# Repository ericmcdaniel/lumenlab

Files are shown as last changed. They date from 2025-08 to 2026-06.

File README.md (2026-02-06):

<p align="center">
  <picture>
    <source media="(prefers-color-scheme: dark)" srcset="assets/lumenlab-logo-dark.png">
    <source media="(prefers-color-scheme: light)" srcset="assets/lumenlab-logo.png">
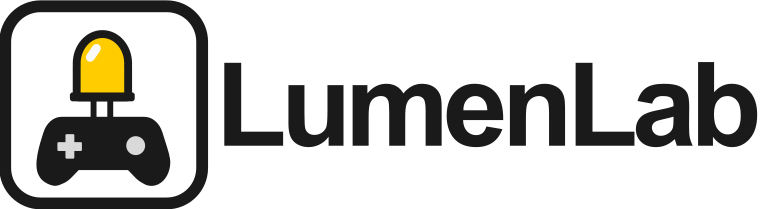
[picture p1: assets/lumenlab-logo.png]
LumenLab Logo
    
  </picture>
</p>
<p align="center">Transforming pixels into a playground</p>

---

__LumenLab__ is an LED strip gaming and entertainment platform designed to transform your space into an interactive playground of light. Powered by an ESP32 microcontroller, displayed through a NeoPixel addressable LED strip, and controlled by a PlayStation 3 game controller, LumenLab brings simple, one-dimensional retro arcade-style games, animations, and ambient lighting to life.
<br>

# Features

LumenLab is composed of two modes. The central mode is its suite of games, but the platform also supports animations and ambient lighting, called scenes. After all it's still an LED strip!

## Games
Using an LED strip as a gaming platform is a unique concept due to the constraint of only having one dimension to interact with. Since *only* the landscape x-axis is available, this constraint compels players to apply creative interpretation during gameplay. This of course is not a modern, feature rich AAA blockbuster with 4K graphics, immersing you in the vision of a world crafted by others. Instead, LumenLab's restriction subtly encourages players to philosophically revisit what it *really* means to play a game down to the core. In its purest form, a game player follows rules and explores boundaries in pursuit of a goal. Gamers encounter conflict and must experiment and adapt to their environment to overcome obstacles. LumenLab forces players to abstractly experience digital gaming at its rawest, most atomic form: structured uncertainty and strategy until mastery is achieved. This has become the manifesto of the LumenLab. **Every individual playing its games has a unique mental concept of what they're experiencing.**

Because LumenLab is restricted to a single dimension composed of an array of LEDs, it's aesthetically reminiscent of retro arcade games. However, LumenLab exploits capabilities unavailable on old 8-bit game consoles. These capabilities include its ability to generate any arbitrary RGB color instead of being limited to 256 colors. Additionally, its UI takes advantage of the broad range of controls and state offered by the PS3 controller such as the number of buttons available and precise analog joy stick/trigger positions, contrasting from a cabinet arcade with only four discrete buttons. There are over six games, each detailed below.

| **Title** | **Description** |
| --- | --- |
| **Recall** |*Recall* is an adaptation of Hasbro's fifty-year-old game [*Simon*](https://en.wikipedia.org/wiki/Simon_(game)), chosen for its familiarity and simplicity. Players easily recognize the format, making it a natural fit for LumenLab’s constraints. Similar to the original, the LED strip flashes a color, and the player must press the matching button on the PS3 controller. Each round adds another color to the sequence, which must be recalled in full and in order.|
| **Phase Evasion** | *Phase Evasion* is a fast, colorful test of reflexes and hand-eye coordination. You are a color-shifting specter that is being pursued by colorful flares. You must match their color at the right moment to phase through them to evade. Gems are scattered throughout periodically. Quickly move over and grab them for bonus points if you dare. As the speed climbs and the screen fills with color, quick reactions and bold moves are the only way to stay in the game. |
| **Light Strike** | *Light Strike* combines the spirit of Atari's [*Space Invaders*](https://en.wikipedia.org/wiki/Space_Invaders) with elements of [*Asteroids*](https://en.wikipedia.org/wiki/Asteroids_(video_game)). As a lone agent in deep space, you enounter waves of predators approaching you from directions sides at varying speeds. Moving freely across the x-axis, and your survival requires defending yourself with your laser pistol. Conserve your ammunition however, your weapon can only fire so many rounds a minute!<br><br>*In development.* |
| **Reflex** | *Reflex* is a fast-moving inspired by the modern arcade game [*Pop the Lock*](https://www.baytekent.com/pop-the-lock/), testing precision and timing under pressure. A moving marker sweeps across the field toward a shifting target. Fire at the perfect moment to score a hit. Each success quickens the pace, reverses the marker's direction, and relocates the target to a new random location. Survive fifty flawless shots to win.<br><br>*In development.* |
| **Spectrum** | *Spectrum* tests your perception of color and precision of control. A random RGB color appears on one end of the display, and you must use the analog stick to recreate it as closely as possible. The closer your match, the higher your score.<br><br>*In development* |
| **Pursuit** | *In development.* Details to be provided soon. |

There are more game ideas in the works, and ideas for some *two-player* games are being considered.

## Scenes

An LED strip entertainment platform would not be complete if it did not include animations and special effects libraries. Inspired by the [WLED project](https://kno.wled.ge/), LumenLab is able to create captivating scenes. Many of them are interactive, for example moving the joystick can change the color, or pressing the directional buttons can change timing.
| **Title** | **Description** |
| --- | --- |
| **Canvas** | *Canvas* lets you choose any color across the RGB range, turning the LED strip into a fully color-customized ambient light source. Press **L1** to rebalance the saturation, **R1** to rebalance the lightness, and **Triangle** to switch to a new random color. |
| **Tempo** | *Tempo* allows you to choose a tempo and strobe lights and trigger light subroutines in response to music.<br><br>*In development.* |
| **Police Siren** | Strobing red and blue lights to look like a law enforcement vehicle.<br><br>*In development.* |
| **Halloween** | Spooky orange and some purple.<br><br>*In development.* |
| **Christmas** | Festive red and green.<br><br>*In development.* |

And more to come.

---

# Experience the Lights in Your Home
Being a hardware-forward project, it is not possible to experience LumenLab without physically having the device. Your options include either having a PCB professionally manufactured and assembled, or soldering your own prototype on a breadboard or perf board using off-the-shelf components.

This guide will walk through both options and their practicality.

## Method A: Professionally Manufactured and Assembled

A custom PCB was designed using KiCad 9 and gives LumenLab a clean aesthetic. All of the schematic files, PCB layout files, BOM, custom symbol libraries, footprints, 3D models, and Gerber files are all found in the `/board` directory. The PCB layout uses the manufacturing capabilities given by [PCBWay](https://www.pcbway.com/). Although you can potentially use any board house of your choosing, the ECAD model was designed with PCBWay's capabilities in mind. Production costs were minimized as much as safely reasonable, such as keeping it's width under 100mm. However for the amount of current that it can potentially consume, thermal safety was factored in, leading to a four-layer design with extra forgiving trace width and copper pours. My manufacturing costs were roughly $50 for ten boards. If you choose to have this manufactured else where, you must adjust for the capabilities of that board house. Your mileage may vary, and by quite a bit too.

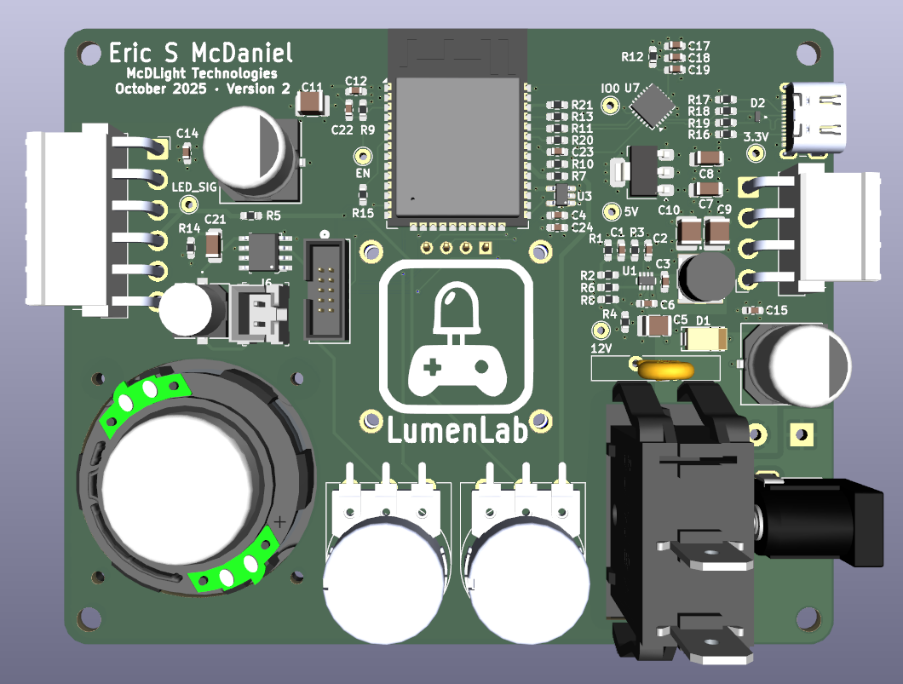
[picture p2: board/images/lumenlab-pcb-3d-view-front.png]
PCB Layout

<p align="center"><i>Figure 1: Front of PCB layout</i></p>

You can view the KiCad schematic, PCB layout, BOM, and 3D rendering of the PCB design [in the *board* directory.](./board/)

## Method B: Hand-Soldering a Prototype

This is the more accessible and classic route especially for DIY enthusiasts, however this can be tricky depending on your background with electronics. Below is the prototype BOM if you'd like to build LumenLab yourself using pre-built modules, THT components, and a breadboard or perfboard. If you're an advanced electronics enthusiast, you may even be able to omit some of the suggestions, such as skipping the buck converter, directly powering the LED strip, and using the 5V power directly from the Vin pin to level shift the LED strip's data signal. These "barebones" alterations are not discussed in this document.

Assembly is remarkably similar to the guidance given on the WLED project. Using their [wiring diagram here](https://kno.wled.ge/basics/wiring-guides/) would be an excellent starting point.

#### <center>Bill of Materials</center>
|  Device | Description |
| --- | --- |
| ESP32 WROOM microcontroller | Only the [WROOM variants](https://docs.espressif.com/projects/esp-dev-kits/en/latest/esp32/esp32-devkitc/index.html) are supported because those are the only variants that support the Bluetooth classic protocol (BR/EDR). You **cannot** substitude the WROOM with other variants, as they all only have support for BLE. |
| WS2815 LED light strip | The 12V variant of the NeoPixel addressable RGB WS2812B. This project uses the 5m (16.4ft), 300 LED strip in black. |
| 12V 10A DC power supply | The 10A supply is required due to the high current demands of displaying white at full brightness. 120W is only the peak power draw, but this typically runs much lower. |
| MP2338 buck converter | Any step down regulator will suffice as long as it outputs 5V and at least 1A. The MP2338 can deliver 2-3A, enough to reliable power the ESP32 during intense gameplay and Bluetooth connectivity. |
| SN74AHCT125N logic level shifter | The ESP32's GPIO lines work using 3.3V signals. Level shifting to 5V ensures that the LED strip's data lines are not lost or corrupted. |
| PlayStation 3 game controller | The input device to navigate the main menu and play games. |
| SSD1306 OLED display module | Using the 0.96" variant, this displays the main menu for mode selection and in game mode is a HUD showing basic statistic like the user's high score. |
| Passive components | Resistors, capacitors, diodes, and fuses as needed for power protection, power stability and smoothing, low-pass filtering, and signal damping to minimize ringing. Refer to your MCU and buck converter's datasheet for guidance on what passives are needed. |

# Software

Regardless of whether your build of LumenLab was professionally manufactured and assembled, or hand-soldered to a perf board, the software is identical between the two approaches. To build this project from scratch, you at minimum need the following frameworks and dependencies:

* **PlatformIO**: A feature-rich ecosystem for embedded development. This framework includes the C/C++ compiler (avr-gcc) needed for MCU development. You can use the toolchain CLI directly, but installing the Visual Studio Code extension is significantly more approachable. [Download PlatformIO here](https://platformio.org/).
* **Python3** (&GreaterEqual;3.6): A dependency of PlatformIO to compile and flash the device. Also used in the virtualizer for local development.

## LED Strip Virtualization

To streamline the software development cycle, a virtualizer was created so that you can simulate what the LEDs would be displaying, but on your computer screen. This enables new features to be developed in comfort without needing to physically connect to the LED strip. Using the ESP32 is still required for development regardless since it's just an emulator for what the ESP32 is actually doing in real time.

When compiling in debug mode, the ESP32 does not transmit color signals to the LED strip and instead sends its color data via USB serial for virtual rendering. When compiling in release mode, the virtualizer and logs are removed. This virtualizer was created using Python, and uses the [ModernGL](https://moderngl.readthedocs.io/en/5.8.2/) library, an OpenGL binding for Python.

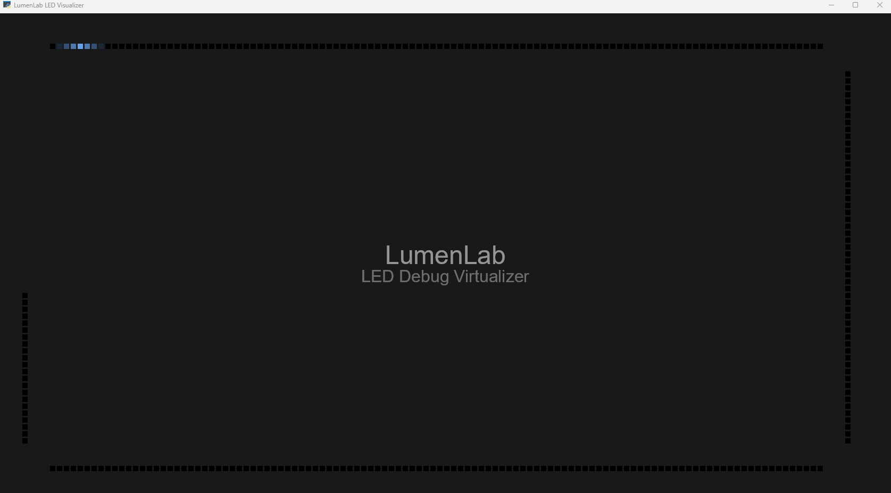
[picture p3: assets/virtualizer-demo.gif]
Virtualizer

<p align="center"><i>Figure 2: Development Virtualizer of two controllable entities, simulating what the LED strip would be rendering</i></p>

## Building the Repository
This section was redacted temporarily because of how rapidly the code base is evolving. The instructions I wrote no longer apply as the Virtualizer was rewritten for speed to send color data via a USB serial connection instead of an open WebSocket connection. Stay tuned.

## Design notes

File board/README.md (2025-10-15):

# Custom PCB Fabrication

The LumenLab was built in two phases. The first phase (labeled as "Version 1") was a prototype that used through-hole components hand-soldered on to several perf boards. This was a good start, especially for making progress in the early stages of the software development, however the components did not work exactly as desired, making its maintanance more of a hassle than it was a benefit. Designing a PCB to be professionally manufactured became a clear and obvious choice, allowing the LumenLab to be scaled into a clean, stable device.

The LumenLab PCB was designed using KiCad 9.0.5

# Schematic
LumenLab schematic
<p align="center">Figure 1. LumenLab schematic and electronic layout</p>

# Bill of Materials
Still to be finalized, however you can [view the tentative list of components here](./bom/ibom.html).

# PCB Layout
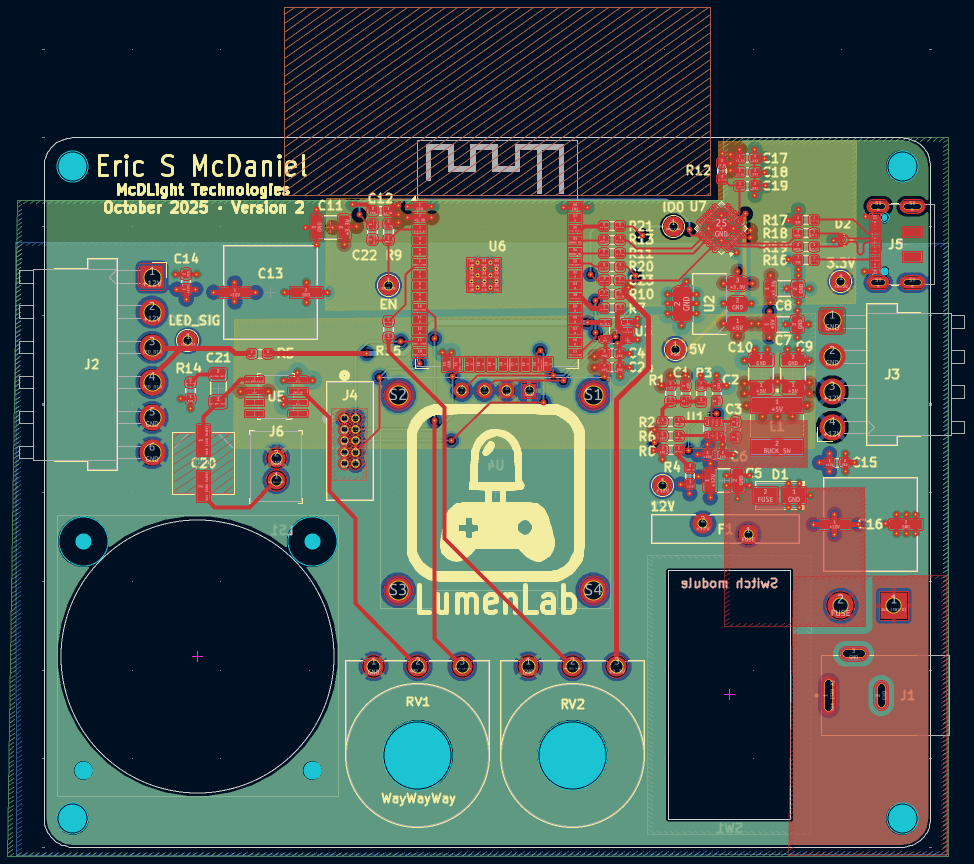
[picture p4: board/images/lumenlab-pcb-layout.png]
LumenLab PCB layout

<p align="center"><i>Figure 2: PCB layout</i></p>

# 3D Preview
PCB Design, front
<p align="center"><i>Figure 3: PCB 3D preview (front)</i></p>

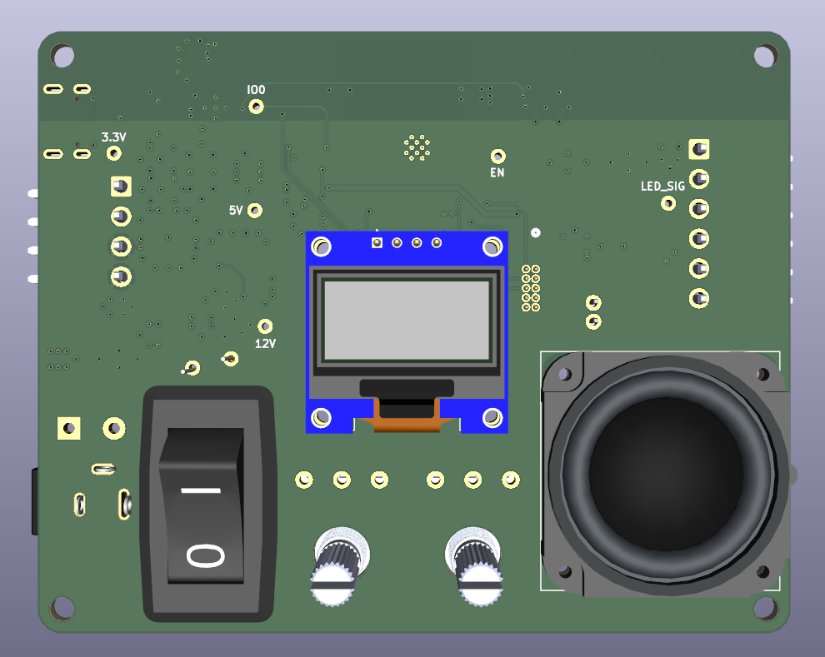
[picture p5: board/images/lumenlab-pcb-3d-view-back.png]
PCB Design, back

<p align="center"><i>Figure 4: PCB 3D preview (back)</i></p>

A 3D printed enclosure will be created to give the final device a clean look.

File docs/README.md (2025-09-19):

# Component Selection

The following details the ICs and components selected, general information, and their justification as to why I selected it where available.

### ESP32-WROOM-32D
* *[Datasheet](./vendor-datasheets/esp32-wroom-32d-datasheet.pdf)*

The only ESP32 variant that support the Bluetooth classic protocol (BR/EDR) are the WROOM variants, eliminating selections such as the more powerful S3. Bluetooth classic is required as the PS3 controller does not support BLE (Bluetooth Low Energy).

**For those using a DevKit for protyping:** You can examine [the GPIO pinout for the ESP32 DevKit here](./vendor-datasheets/esp32-pinout.avif). This is the pinout for my particular DevKit. Your mileage may vary.

### MP2338 step down buck converter
* *[Datasheet](./vendor-datasheets/mp2338-datasheet.pdf)*
* *[Distributor](https://www.digikey.com/en/products/detail/monolithic-power-systems-inc/MP2338GTL-Z/15966227)*
* *Manufacturer:* Monolithic Power Systems, Inc.
* *Package:* SOT-583

### AP7361C LDO regulator
* *[Datasheet](./vendor-datasheets/ap7361c-datasheet.pdf)*
* *[Distributor](https://www.digikey.com/en/products/detail/diodes-incorporated/AP7361C-33E-13/5638317)*
* *Manufacturer:* Diodes, Inc.
* *Package:* SOT-223-3

I originally selected the AMS1117 by EVVOSEMI as that is what's provided on the ESP32-WROOM-32 DevKit, however the AP7361C is more efficient due to it's 340 mV drop at 1A (compared to AMS1117's 1.2V drop at 1A). The AP7361C also has a high PSRR with 75dB @ 1kHz, however the AMS1117's PSRR is the same under similar conditions.

### SN74AHC1G125 Logic Level Shifter
* *[Datasheet](./vendor-datasheets/sn74ahc1g125-logic-level-shifter-datasheet.pdf)*
* *[Distributor](https://www.digikey.com/en/products/detail/texas-instruments/SN74AHC1G125DCKR/373804)*
* *Manufacturer:* Texas Instruments, Inc.
* *Package:* SC-70-5

This one has simply a single gate instead of the quad-gate IC used on the perfboard. I chose the SOT-23-5 package for troubleshooting flexibility, but it's also made in a SC-70-5 package (SN74AHC1G125DCKR) if space is a concern.

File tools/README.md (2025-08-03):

# LED Virtualizer

An LED visualizer using fastplotlib that listens for UDP color commands and updates a ring of virtual LEDs.

## Usage

Setup your virtual environment first
``` bash
cd tools
python -m venv .venv

# For Windows:
.venv\Scripts\activate

# Otherise, for *nix
source .venv/bin/activate
```

Lastly, install the dependencies and run the virtualizer
``` bash
pip install -r requirements.txt
python virtualization.py
```

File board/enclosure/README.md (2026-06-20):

# 3D-Printed Enclosure

### Prototype Version 1

The enclosure can be 3D-printed in multi-color and single-color 3D printers. The lid is printed separate from the body.

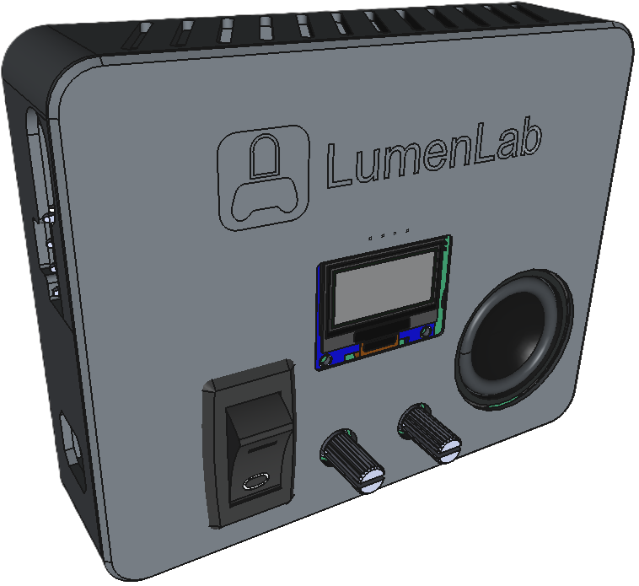
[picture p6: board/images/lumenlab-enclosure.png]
LumenLab enclosure


### Prototype Version 2

For my second build, the LumenLab will be installed hanging upside-down to preserve shelf space. It features a controller mount so that you can return the controller after use.

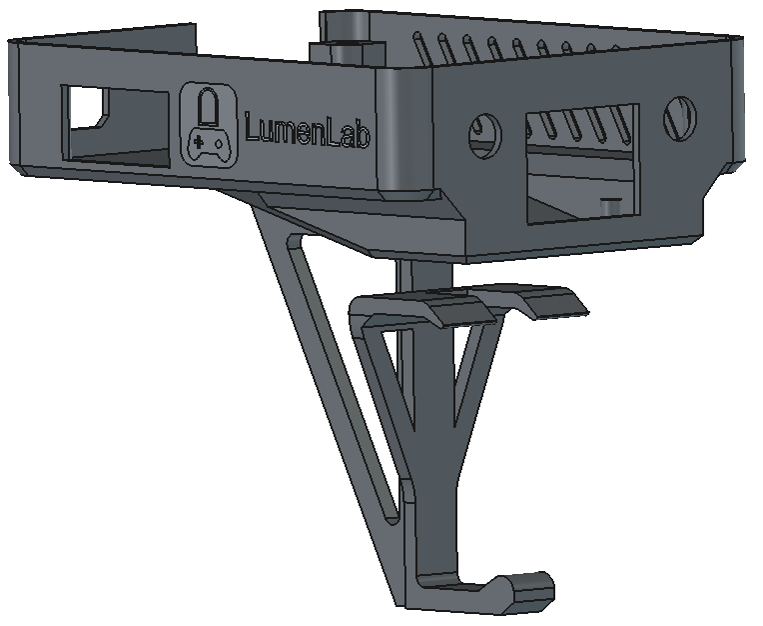
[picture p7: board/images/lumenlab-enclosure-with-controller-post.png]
LumenLab Enclosure v2 with controller post


# Current Version (v3)

My previous design served me well for my needs, but it isn't an ideal solution for most people. This final version is the same as before, but flips the controller upside down so that it can become a platform gaming system. Resting it on a shelf or countertop allows you to leave it in place without permanently mounting it on your walls or furniture.

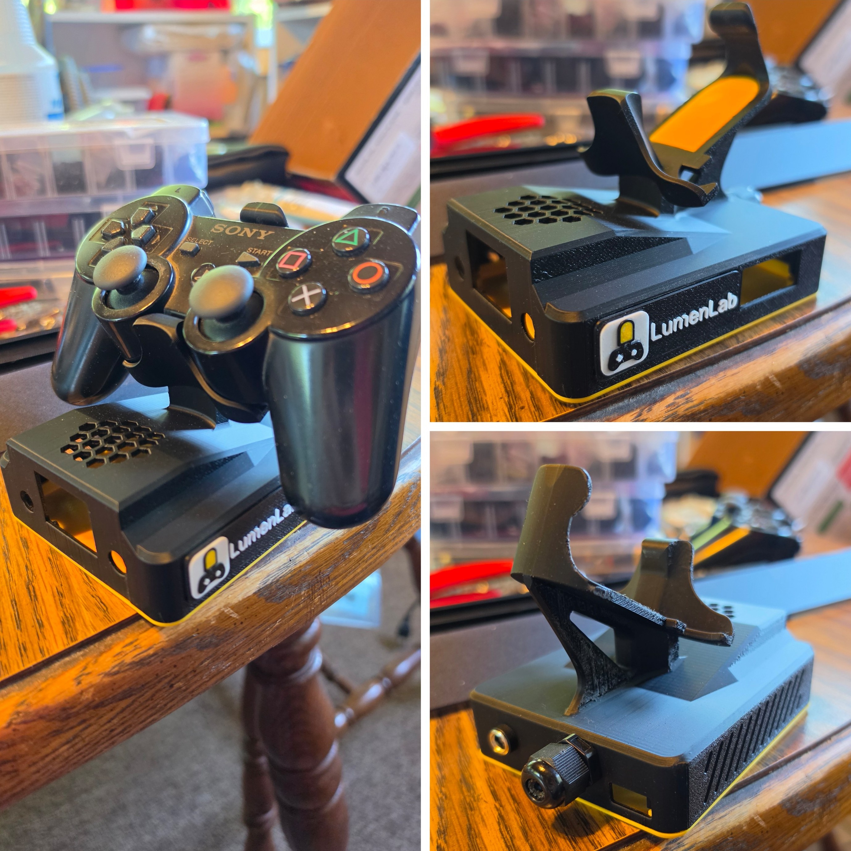
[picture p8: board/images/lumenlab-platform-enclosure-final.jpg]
Physical print


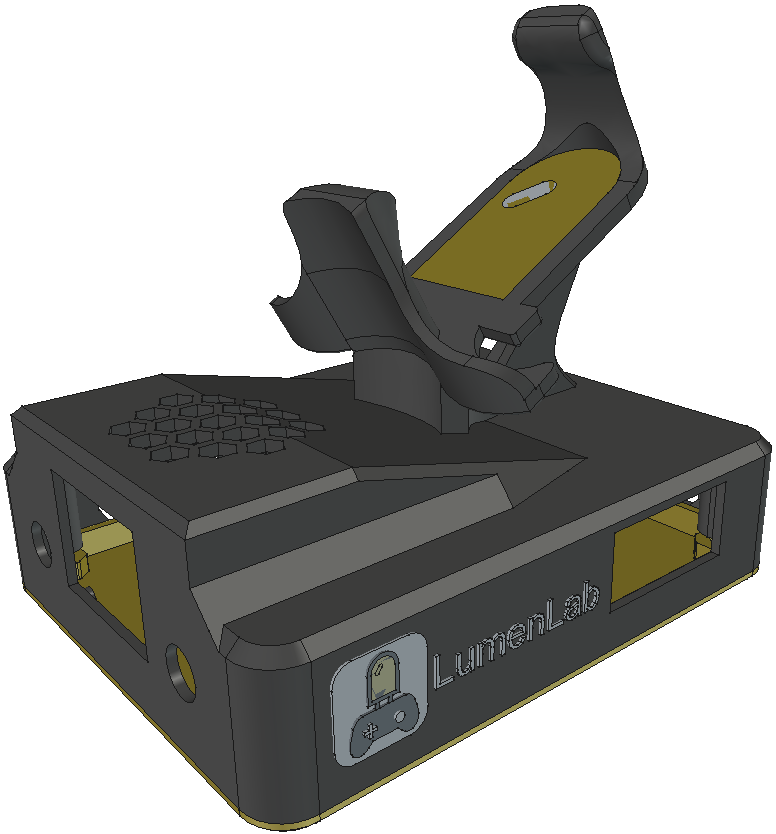
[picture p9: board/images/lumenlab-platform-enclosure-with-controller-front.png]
Front edge angle of the LumenLab enclosure v3, with a controller saddle


*Front edge angle of the LumenLab enclosure v3, with a controller saddle*

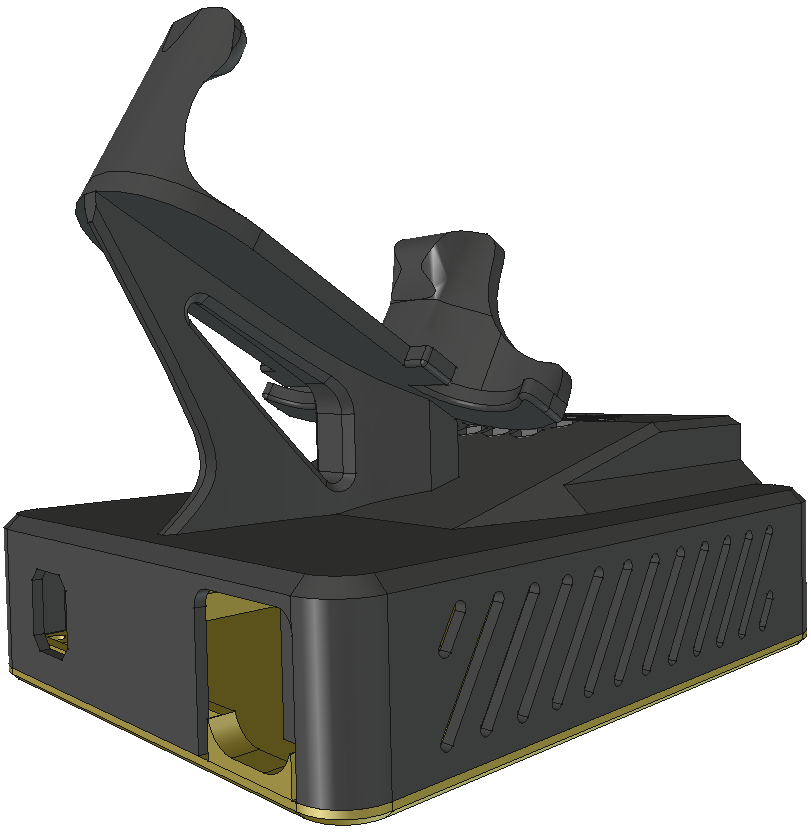
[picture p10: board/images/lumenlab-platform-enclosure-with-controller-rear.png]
Rear edge angle of the LumenLab enclosure v3, with a controller saddle


*Rear edge angle of the LumenLab enclosure v3, with a controller saddle*

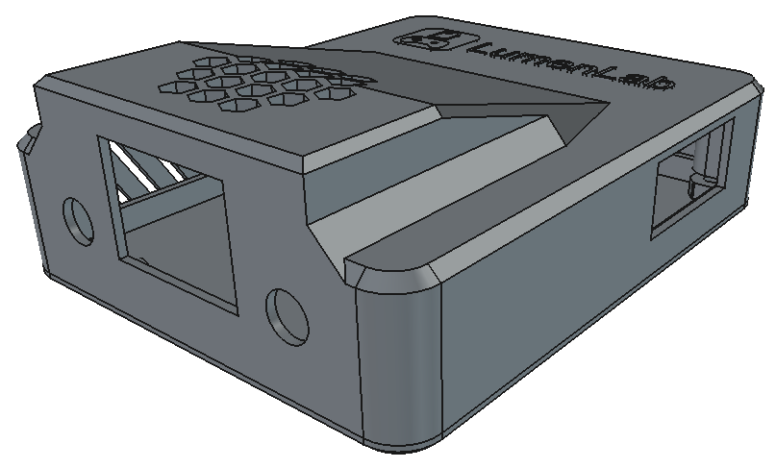
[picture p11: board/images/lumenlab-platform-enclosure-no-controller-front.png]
Front edge angle of the LumenLab enclosure v3, no controller saddle


*Front edge angle of the LumenLab enclosure v3, no controller saddle*

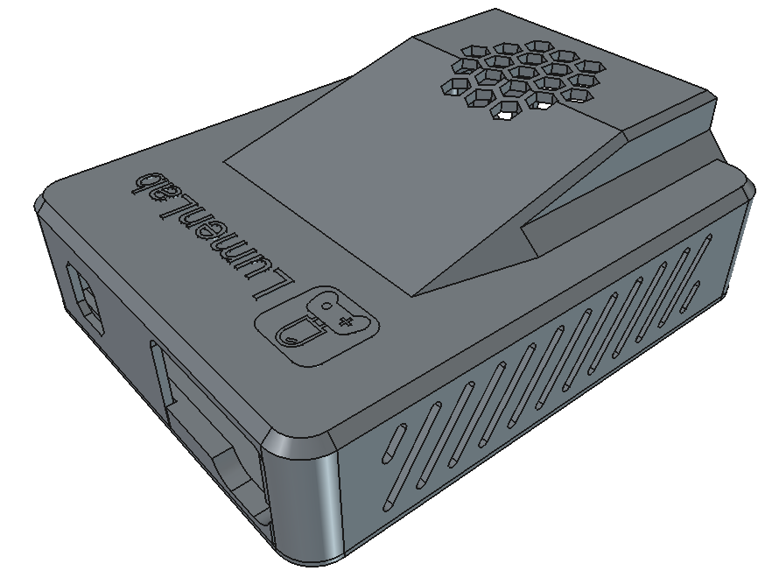
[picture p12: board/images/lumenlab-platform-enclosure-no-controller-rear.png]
Rear edge angle of the LumenLab enclosure v3, no controller saddle


*Rear edge angle of the LumenLab enclosure v3, no controller saddle*

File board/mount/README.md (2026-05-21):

# 3D-Printed Mounting Bracket

A bracket so that you can mount these on the corner. It's assembled from two pieces. The first is the actual bracket which you fasten the LED strip to, on to the wall. In replacement of the classic aluminum rails, this bracket requires a black LED acrylic sheet cut to 34mm by 250mm (or more).

For this early prototype model, I went forward with the [Chemcast Black LED Acrylic Sheets from California-based TAP Plastics](https://www.tapplastics.com/product/plastics/cut_to_size_plastic/black_led_sheet/668) for <$20, however you can purchase from any supplier as long as the rail length is strictly 34mm. The width can be any size you set your bracket to.

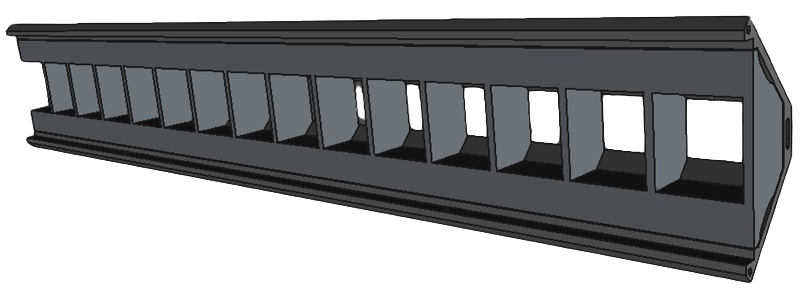
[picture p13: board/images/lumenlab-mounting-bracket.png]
LumenLab bracket


## Prototype Version 2

Still experimental, but some tweaks were made on how the LED is placed within each cell.

#### Front
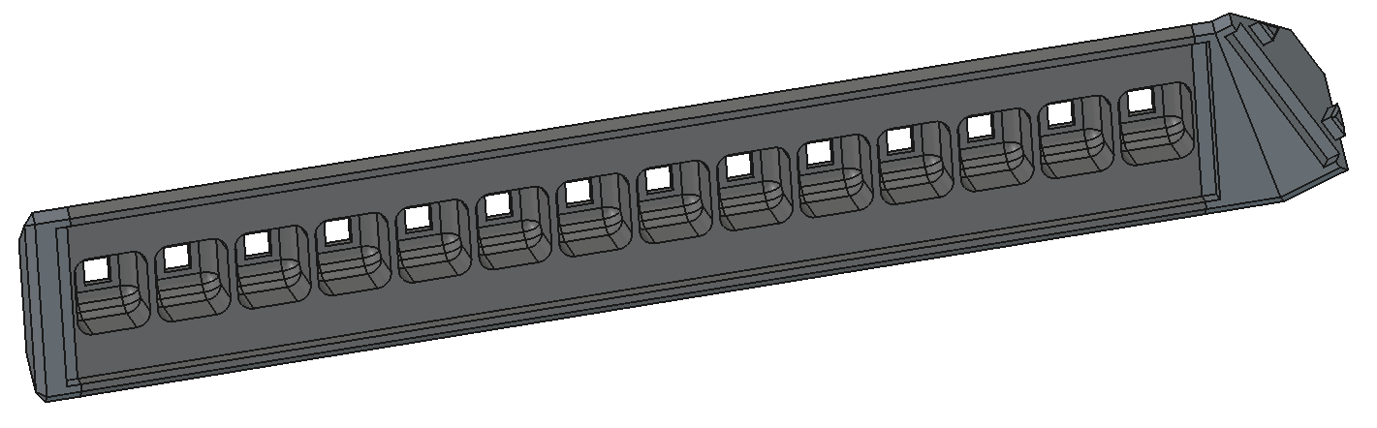
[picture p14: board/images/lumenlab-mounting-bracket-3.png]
Front of LumenLab bracket v2


#### Back
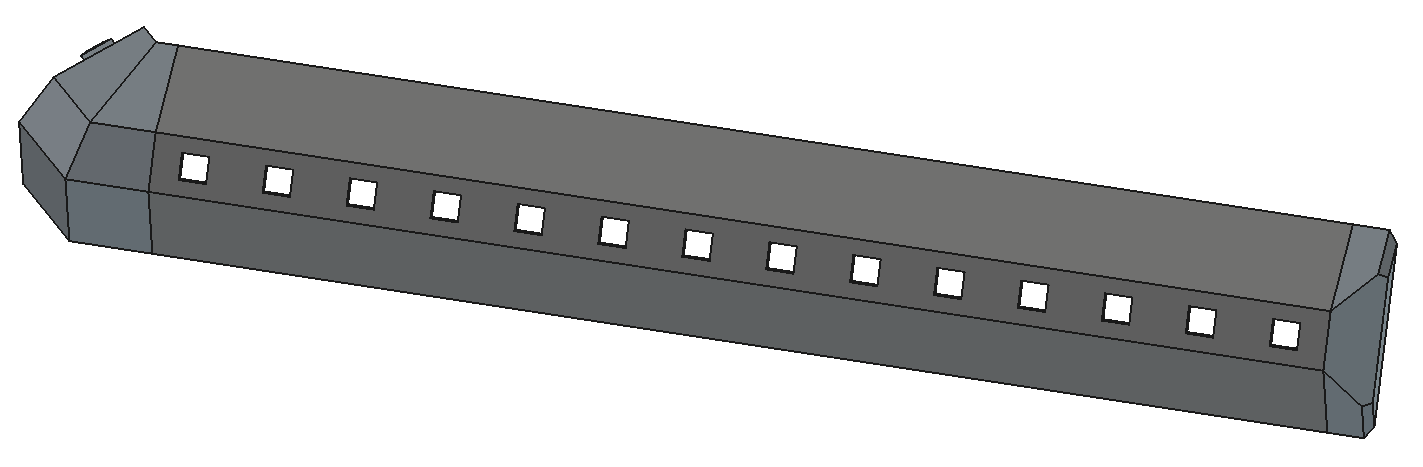
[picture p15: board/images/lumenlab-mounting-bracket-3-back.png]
Back of LumenLab bracket v2


## Version 3

This version abandons the LED black acrylic diffuser in favor of a different diffuser. The acrylic looks fantastic, however it makes all the edges blurry. With that material, I can't get crisp edges while full diffusion of color, avoiding LED hotspots. I found another diffusion material meant for photography, but it comes in paper-sized sheets and needs to be cut to size. To reduce cost, I changed the geometry of the face where the acrylic get applied, saving material cost.

Additionally, the end caps were refined so that there is space for decoupling capacitors right at the start (and end) of the LED strip. This is done directly on the board as well, but this is an additional smoothing layer so that I don't have to be extremely limited on the length of the cable leading to the LED strip.

As with the previous design, the LEDs are placed behind the cavity. If that side faces outward in any way and is visible, black electrical tape can be applied on the back to side the LED strip (assuming you print in black).

#### Front
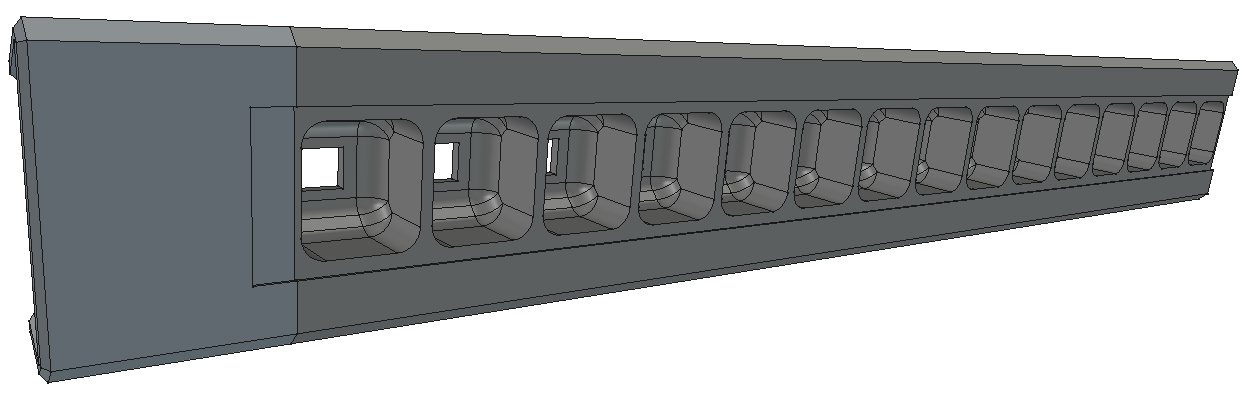
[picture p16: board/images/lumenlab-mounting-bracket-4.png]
Front of LumenLab bracket v3


#### Back
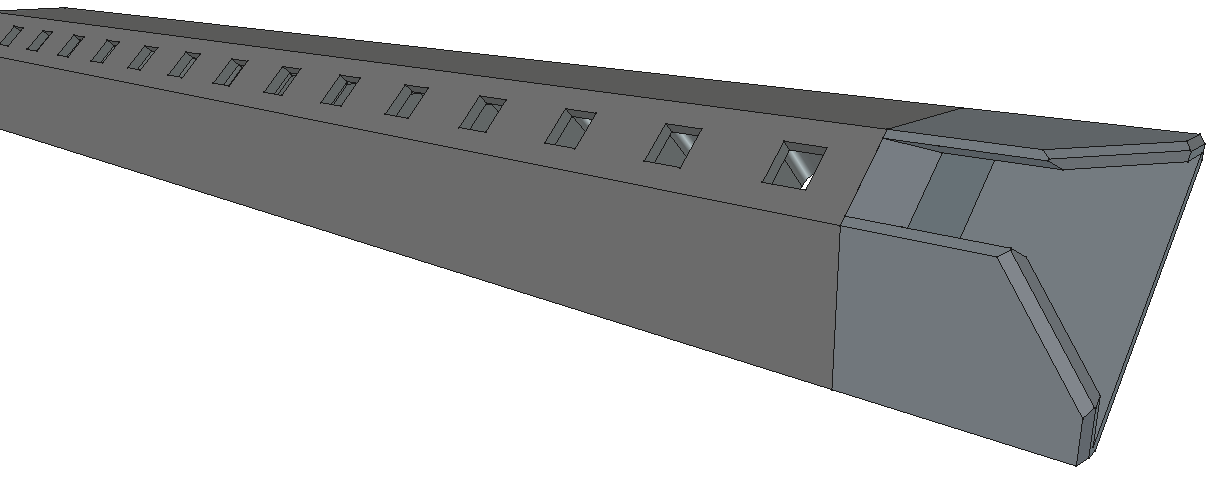
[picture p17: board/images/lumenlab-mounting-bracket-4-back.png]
Back of LumenLab bracket v3


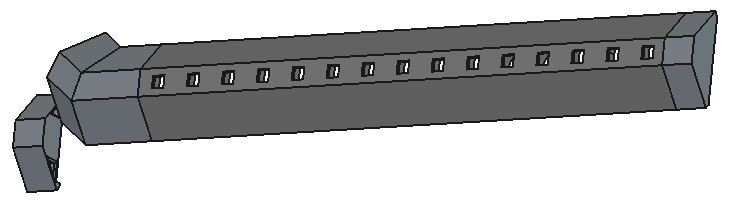
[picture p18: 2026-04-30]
board/images/lumenlab-mounting-bracket-2-back.png

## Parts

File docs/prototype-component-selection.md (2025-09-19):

# Perfboard Prototype Component Selection

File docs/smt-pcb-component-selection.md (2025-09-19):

# Component Guide for Professionally Manufactured SMT PCB

SN74AHC1G125 - a single gate logic level shifter

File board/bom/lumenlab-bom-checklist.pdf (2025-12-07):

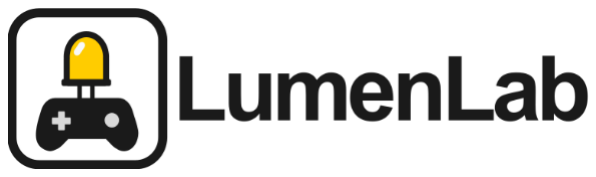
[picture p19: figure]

# Microsoldering BOM Checklist

Reference Manufacturer Name | Description | Qty Applied
U3 | Texas Instruments | IC BUFF NON-INVERT 5.5V SOT-23-5 | 1
D1 | Littelfuse Inc. | TVS DIODE 12VWM 19.9VC DO214AC | 1
F1 | Littelfuse Inc. | PTC RESET FUSE 16V 10A RADIAL | 1
U1 | Monolithic Power Systems Inc. | IC REG BUCK ADJ 3A SOT583 | 1
J1 | Tensility International Corp | CONN JACK R/A PCB 5.5X2.1MM | 1
C5 | Samsung Electro-Mechanics | CAP CER 22UF 16V X7R 1210 | 4
C9 | Samsung Electro-Mechanics | CAP CER 22UF 16V X7R 1210 | 4
C10 | Samsung Electro-Mechanics | CAP CER 22UF 16V X7R 1210 | 4
C11 | Samsung Electro-Mechanics | CAP CER 22UF 16V X7R 1210 | 4
C3 | YAGEO | CAP CER 0.1UF 16V X7R 0603 | 12
C4 | YAGEO | CAP CER 0.1UF 16V X7R 0603 | 12
C6 | YAGEO | CAP CER 0.1UF 16V X7R 0603 | 12
C12 | YAGEO | CAP CER 0.1UF 16V X7R 0603 | 12
C14 | YAGEO | CAP CER 0.1UF 16V X7R 0603 | 12
C15 | YAGEO | CAP CER 0.1UF 16V X7R 0603 | 12
C17 | YAGEO | CAP CER 0.1UF 16V X7R 0603 | 12
C18 | YAGEO | CAP CER 0.1UF 16V X7R 0603 | 12
C19 | YAGEO | CAP CER 0.1UF 16V X7R 0603 | 12
C22 | YAGEO | CAP CER 0.1UF 16V X7R 0603 | 12
C23 | YAGEO | CAP CER 0.1UF 16V X7R 0603 | 12
C24 | YAGEO | CAP CER 0.1UF 16V X7R 0603 | 12
R4 | Panasonic Electronic Components | RES SMD 191K OHM 1% 1/10W 0603 | 1

R8 | Stackpole Electronics Inc | RES 49.9K OHM 1% 1/10W 0603 | 1
C2 | Walsin Technology Corporation | CAP CER 0.022UF 50V X7R 0603 | 1
C1 | Walsin Technology Corporation | CAP CER 300PF 50V C0G/NP0 0603 | 1
R1 | Bourns Inc. | RES SMD 90.9K OHM 1% 1/10W 0603 | 1
L1 | Murata Electronics | FIXED IND 6.8UH 3.4A 35 MOHM SMD | 1
R11 | Stackpole Electronics Inc | RES 1K OHM 1% 1/10W 0603 | 3
R13 | Stackpole Electronics Inc | RES 1K OHM 1% 1/10W 0603 | 3
R15 | Stackpole Electronics Inc | RES 1K OHM 1% 1/10W 0603 | 3
C21 | KYOCERA AVX | CAP CER 0.05UF 50V X7R 1206 | 1
C20 | Rubycon | CAP ALUM 220UF 20% 10V SMD | 1
U5 | Texas Instruments | IC AMP CLASS AB MONO 325MW 8SOIC | 1
RV1 | TT Electronics/BI | POT 10K OHM 1/10W PLASTIC LOG | 1
RV2 | Same Sky (Formerly CUI Devices) | POT 10K OHM 1/8W CARBON LINEAR | 1
U2 | Diodes Incorporated | IC REG LINEAR 3.3V 1A SOT-223-3 | 1
C7 | Taiyo Yuden | CAP CER 4.7UF 10V X7R 1206 | 2
C8 | Taiyo Yuden | CAP CER 4.7UF 10V X7R 1206 | 2
R5 | TE Connectivity Passive Product | RES SMD 330 OHM 1% 1/10W 0603 | 1
J4 | CNC Tech | CONN HEADER VERT 10POS 1.27MM | 1
U6 | Espressif Systems | RF TXRX MOD BT WIFI PCB TH SMD | 1
J5 | JAE Electronics | CONN RCP USB2.0 TYP C 24P SMD RA | 1
U7 | Silicon Labs | IC USB TO UART BRIDGE QFN24 | 1
D2 | Texas Instruments | TVS DIODE 3.6VWM 8.4VC 3X2SON | 1
R14 | Stackpole Electronics Inc | RES 10 OHM 1% 1/10W 0603 | 1
R16 | Stackpole Electronics Inc | RES 5.1K OHM 1% 1/10W 0603 | 2
R17 | Stackpole Electronics Inc | RES 5.1K OHM 1% 1/10W 0603 | 2
R18 | Stackpole Electronics Inc | RES 22 OHM 1% 1/10W 0603 | 2
R19 | Stackpole Electronics Inc | RES 22 OHM 1% 1/10W 0603 | 2
J2 | JST Sales America Inc. | CONN HEADER R/A 6POS 3.96MM | 1
J3 | JST Sales America Inc. | CONN HEADER R/A 4POS 3.96MM | 1
| JST Sales America Inc. | CONN RCPT HSG 6POS 3.96MM | 1

| JST Sales America Inc. | CONN RCPT HSG 4POS 3.96MM | 1
C13 | Chemi-Con | CAP ALUM 1000UF 20% 25V SMD | 2
C16 | Chemi-Con | CAP ALUM 1000UF 20% 25V SMD | 2
R20 | Panasonic Electronic Components | RES SMD 4.7K OHM 1% 1/10W 0603 | 2
R21 | Panasonic Electronic Components | RES SMD 4.7K OHM 1% 1/10W 0603 | 2
R7 | Panasonic Electronic Components | RES SMD 33 OHM 1% 1/10W 0603 | 1
SW1 | Würth Elektronik | SWITCH ROCKER SPST 16A 250V | 1
LS1 | Challenge Electronics | SPEAKER 8OHM 3W 83DB | 1
J6 | Hirose Electric Co Ltd | CONN HEADER VERT 2POS 2.5MM | 1
R2 | YAGEO | RES 10K OHM 1% 1/10W 0603 | 10
R3 | YAGEO | RES 10K OHM 1% 1/10W 0603 | 10
R6 | YAGEO | RES 10K OHM 1% 1/10W 0603 | 10
R9 | YAGEO | RES 10K OHM 1% 1/10W 0603 | 10
R10 | YAGEO | RES 10K OHM 1% 1/10W 0603 | 10
R12 | YAGEO | RES 10K OHM 1% 1/10W 0603 | 10

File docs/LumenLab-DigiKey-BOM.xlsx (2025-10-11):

Country of Origin may be different at time of shipment.
The HTSUS and ECCN information shown is for informational purposes only and is not a representation or warranty as to the accuracy or reliability of these classifications. All information is provided "as is" and is subject to change without notice. Any use made of the information provided is without recourse to Digi-Key and at the user's risk.
Index | Manufacturer Part Number | Manufacturer Name | Description | Lead Time | Availability | Stock Status | Attrition % | Requested Quantity 1 | Pack Quantity 1 | Pack Type 1 | Digi-Key Part Number 1 | Unit Price 1 | Extended Price 1 | Minimum Order Quantity 1 | Customer Reference | Requested Part Number | Lead Weeks | Datasheet | Reference Designator | US Import Tariff | Note | Part Status | RoHS Status | Moisture Sensitivity Level (MSL) | ECCN | HTSUS | Country of Origin | Environmental Information | Original Part numbers | Image | Product Notes
1 | SN74AHCT1G125DBVR | Texas Instruments | IC BUFF NON-INVERT 5.5V SOT-23-5 |  | 40,256 | In Stock |  | 1 | 1 | Cut Tape (CT) | 296-4708-1-ND | 0.14000 | $0.14 | 1 | U3 | 296-4708-2-ND | 12 | https://www.ti.com/general/docs/suppproductinfo.tsp?distId=10 |  | N/A |  | Active | ROHS3 Compliant | 1 (Unlimited) | EAR99 | 8542.39.0070 | United States |  | 296-4708-2-ND | https://mm.digikey.com/Volume0/opasdata/d220001/medias/images/4180/296%7E4073253-4%7EDBV%7E5.JPG
2 | SMAJ12CA | Littelfuse Inc. | TVS DIODE 12VWM 19.9VC DO214AC |  | 19,253 | In Stock |  | 1 | 1 | Cut Tape (CT) | SMAJ12CALFCT-ND | 0.28000 | $0.28 | 1 | D1 | SMAJ12CALFTR-ND | 12 | https://www.littelfuse.com/assetdocs/tvs-diodes-smaj-datasheet?assetguid=13c2a823-03b8-4d1f-9ddc-9b44670aed9d |  | May apply on shipments to the U.S. |  | Active | ROHS3 Compliant | 1 (Unlimited) | EAR99 | 8541.10.0080 | China | https://www.littelfusebusinesscenter.com/LFWeb/rohs_upload/RoHS_Certificate_of_Compliance/CoC_RoHS9_SMAJ12CA_05-08-2018.pdf | SMAJ12CALFTR-ND | https://mm.digikey.com/Volume0/opasdata/d220001/medias/images/4828/118%7EDO214AC%28SMA%29%7E%7E2.JPG
3 | AGRF1000-2 | Littelfuse Inc. | PTC RESET FUSE 16V 10A RADIAL |  | 671 | In Stock |  | 1 | 1 | Cut Tape (CT) | 18-AGRF1000-2CT-ND | 1.31000 | $1.31 | 1 | F1 | 18-AGRF1000-2TR-ND | 15 | https://www.littelfuse.com/assetdocs/littelfuse-ptc-radial-leaded-agrf-datasheet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 |  | May apply on shipments to the U.S. |  | Active | ROHS3 Compliant | Not Applicable | EAR99 | 8533.40.8070 | China |  | 18-AGRF1000-2TR-ND | https://mm.digikey.com/Volume0/opasdata/d220001/medias/images/404/AGRF.jpg
4 | MP2338GTL-Z | Monolithic Power Systems Inc. | IC REG BUCK ADJ 3A SOT583 |  | 265 | In Stock |  | 1 | 1 | Cut Tape (CT) | 1589-MP2338GTL-ZCT-ND | 1.55000 | $1.55 | 1 | U1 | 1589-MP2338GTL-ZTR-ND | 12 | https://www.monolithicpower.com/en/documentview/productdocument/index/version/2/document_type/Datasheet/lang/en/sku/MP2338GTL/document_id/9461/ |  | N/A |  | Active | ROHS3 Compliant | 1 (Unlimited) | EAR99 | 8542.39.0070 | China | https://media.monolithicpower.com/mps_cms_document/m/o/monolithic_power_systems_environmental_compliance_declaration_august_2021.pdf | 1589-MP2338GTL-ZTR-ND | https://mm.digikey.com/Volume0/opasdata/d220001/medias/images/3940/1589%7ESOT583%7E%7E8.jpg | Non Cancellable Non Returnable.
5 | 54-00166 | Tensility International Corp | CONN JACK R/A PCB 5.5X2.1MM |  | 12,209 | In Stock |  | 1 | 1 | Tray | 839-54-00166-ND | 0.54000 | $0.54 | 1 | J1 | 839-54-00166-ND | 16 | https://tensility.s3.us-west-2.amazonaws.com/uploads/pdffiles/54-00166.pdf |  | May apply on shipments to the U.S. |  | Active | ROHS3 Compliant | 1 (Unlimited) | EAR99 | 8536.69.4010 | China |  | 839-54-00166-ND | https://mm.digikey.com/Volume0/opasdata/d220001/medias/images/210/MFG_54-00166.jpg
6 | 16SEPF1000M+T | Panasonic Electronic Components | CAP ALUM POLY 1000UF 20% 16V TH |  | 504 | In Stock |  | 2 | 2 | Cut Tape (CT) | 10-16SEPF1000M+TCT-ND | 1.88000 | $3.76 | 1 | C13/C16 | 10-16SEPF1000M+TTB-ND | 26 | https://industrial.panasonic.com/ww/products/pt/os-con/models/16SEPF1000M |  | N/A |  | Active | ROHS3 Compliant | Not Applicable | EAR99 | 8532.22.0020 | Japan | https://industrial.panasonic.com/cdbs/www-cgi/auto-publishing.cgi?type=ROSU&region=WW&layer=4&cd=AAB8009 | 10-16SEPF1000M+TTB-ND | https://mm.digikey.com/Volume0/opasdata/d220001/medias/images/2588/OS-CON%2C%20SEPF%2010mm.jpg
7 | CL32B226MOJNNNE | Samsung Electro-Mechanics | CAP CER 22UF 16V X7R 1210 |  | 53,532 | In Stock |  | 4 | 4 | Cut Tape (CT) | 1276-3395-1-ND | 0.39000 | $1.56 | 1 | C5/C9/C10/C11 | 1276-3395-2-ND | 31 | https://weblib.samsungsem.com/mlcc/mlcc-ec-data-sheet.do?partNumber=CL05Y105KP6VPN |  | May apply on shipments to the U.S. |  | Active | ROHS3 Compliant | 1 (Unlimited) | EAR99 | 8532.24.0020 | China | https://www.samsungsem.com/files/fileDown.do?key=ed1dfdfa-645e-4252-b707-17f9b1502dd1|https://www.samsungsem.com/global/support/certificate/product-stewardship.do | 1276-3395-2-ND | https://mm.digikey.com/Volume0/opasdata/d220001/medias/images/2537/Ceramic-Capacitor-CL-Series.jpg
8 | CC0603KRX7R7BB104 | YAGEO | CAP CER 0.1UF 16V X7R 0603 |  | 6,717,363 | In Stock |  | 11 | 11 | Cut Tape (CT) | 311-1088-1-ND | 0.00800 | $0.09 | 1 | C3/C4/C6/C12/C14/C15/C17/C18/C19/C22/C23 | 311-1088-2-ND | 16 | https://www.yageo.com/en/Chart/Download/pdf/CC0603KRX7R7BB104 |  | N/A |  | Active | ROHS3 Compliant | 1 (Unlimited) | EAR99 | 8532.24.0020 | Taiwan |  | 311-1088-2-ND | https://mm.digikey.com/Volume0/opasdata/d220001/medias/images/4322/cut-tape-render.jpg
9 | ERJ-3EKF1913V | Panasonic Electronic Components | RES SMD 191K OHM 1% 1/10W 0603 |  | 41,540 | In Stock |  | 1 | 1 | Cut Tape (CT) | P191KHCT-ND | 0.10000 | $0.10 | 1 | R4 | P191KHTR-ND | 12 | https://industrial.panasonic.com/cdbs/www-data/pdf/RDA0000/AOA0000C304.pdf |  | May apply on shipments to the U.S. |  | Active | ROHS3 Compliant | 1 (Unlimited) | EAR99 | 8533.21.0030 | China | https://industrial.panasonic.com/cdbs/www-cgi/auto-publishing.cgi?type=ROSU&region=WW&layer=4&cd=AOA0002 | P191KHTR-ND | https://mm.digikey.com/Volume0/opasdata/d220001/medias/images/2606/MFG_ERJ-P6W%20Series.jpg
10 | RMCF0603FT49K9 | Stackpole Electronics Inc | RES 49.9K OHM 1% 1/10W 0603 |  | 381,316 | In Stock |  | 1 | 1 | Cut Tape (CT) | RMCF0603FT49K9CT-ND | 0.10000 | $0.10 | 1 | R8 | RMCF0603FT49K9TR-ND | 17 | https://www.seielect.com/catalog/SEI-RMCF_RMCP.pdf |  | N/A |  | Active | ROHS3 Compliant | 1 (Unlimited) | EAR99 | 8533.21.0030 | Taiwan | https://www.seielect.com/catalog/SEI-RoHS_Compliance_Status.pdf|https://www.seielect.com/catalog/reach.pdf|https://www.seielect.com/catalog/sei-coc%20prop%2065.pdf | RMCF0603FT49K9TR-ND | https://mm.digikey.com/Volume0/opasdata/d220001/medias/images/4849/738_0603.jpg
11 | 0603B223K500CT | Walsin Technology Corporation | CAP CER 0.022UF 50V X7R 0603 |  | 1,285,810 | In Stock |  | 1 | 1 | Cut Tape (CT) | 1292-1417-1-ND | 0.10000 | $0.10 | 1 | C2 | 1292-1417-2-ND | 20 | https://www.passivecomponent.com/wp-content/uploads/datasheet/WTC_MLCC_General_Purpose.pdf |  | N/A |  | Active | ROHS3 Compliant | 1 (Unlimited) | EAR99 | 8532.24.0020 | Taiwan | http://www.passivecomponent.com/download/reach_rohs_compliance_declaration-2/?wpdmdl=1343 | 1292-1417-2-ND | https://mm.digikey.com/Volume0/opasdata/d220001/derivates/6/200/513/768/0603-%281608-Metric%29-0%2C90mm_web%28640x640%29.jpg
12 | 0603N301J500CT | Walsin Technology Corporation | CAP CER 300PF 50V C0G/NP0 0603 |  | 24,351 | In Stock |  | 1 | 1 | Cut Tape (CT) | 1292-1516-1-ND | 0.10000 | $0.10 | 1 | C1 | 1292-1516-2-ND | 20 | https://www.passivecomponent.com/wp-content/uploads/datasheet/WTC_MLCC_General_Purpose.pdf |  | N/A |  | Active | ROHS3 Compliant | 1 (Unlimited) | EAR99 | 8532.24.0020 | Taiwan | http://www.passivecomponent.com/download/reach_rohs_compliance_declaration-2/?wpdmdl=1343 | 1292-1516-2-ND | https://mm.digikey.com/Volume0/opasdata/d220001/derivates/6/200/513/768/0603-%281608-Metric%29-0%2C90mm_web%28640x640%29.jpg
13 | CR0603-FX-9092ELF | Bourns Inc. | RES SMD 90.9K OHM 1% 1/10W 0603 |  | 140,014 | In Stock |  | 1 | 1 | Cut Tape (CT) | CR0603-FX-9092ELFCT-ND | 0.10000 | $0.10 | 1 | R1 | CR0603-FX-9092ELFTR-ND | 21 | https://bourns.com/docs/product-datasheets/cr.pdf?sfvrsn=574d41f6_14 |  | N/A |  | Active | ROHS3 Compliant | 1 (Unlimited) | EAR99 | 8533.21.0030 | Taiwan | https://www.bourns.com/docs/Product-MDS/cr0603_mds.pdf|https://mm.digikey.com/Volume0/opasdata/d220001/medias/docus/6657/Bourns%20REACH%20247%20Jan%202025%20Statement.pdf|https://www.bourns.com/docs/rohs-cofc/crx_coc.pdf?sfvrsn=db3a74f6_10 | CR0603-FX-9092ELFTR-ND | https://mm.digikey.com/Volume0/opasdata/d220001/medias/images/505/CR0603-%281608-Metric%29.jpg
14 | RMCF0603JT10K0 | Stackpole Electronics Inc | RES 10K OHM 5% 1/10W 0603 |  | 1,966,736 | In Stock |  | 6 | 6 | Cut Tape (CT) | RMCF0603JT10K0CT-ND | 0.10000 | $0.60 | 1 | R2/R3/R6/R9/R10/R12 | RMCF0603JT10K0CT-ND | 17 | https://www.seielect.com/catalog/SEI-RMCF_RMCP.pdf |  | N/A |  | Active | ROHS3 Compliant | 1 (Unlimited) | EAR99 | 8533.21.0030 | Taiwan | https://www.seielect.com/catalog/SEI-RoHS_Compliance_Status.pdf|https://www.seielect.com/catalog/reach.pdf|https://www.seielect.com/catalog/sei-coc%20prop%2065.pdf | RMCF0603JT10K0CT-ND | https://mm.digikey.com/Volume0/opasdata/d220001/medias/images/4322/cut-tape-render.jpg
15 | 1264EY-6R8M=P3 | Murata Electronics | FIXED IND 6.8UH 3.4A 35 MOHM SMD |  | 12,906 | In Stock |  | 1 | 1 | Cut Tape (CT) | 490-14065-1-ND | 0.39000 | $0.39 | 1 | L1 | 490-14065-1-ND | 14 | https://search.murata.co.jp/Ceramy/image/img/P02/J(E)TE243B-0044_DG6050C_reference.pdf |  | N/A |  | Active | ROHS3 Compliant | 1 (Unlimited) | EAR99 | 8504.50.8000 | Vietnam |  | 490-14065-1-ND | https://mm.digikey.com/Volume0/opasdata/d220001/medias/images/837/MFG_DG6045C%2CDG6050C.JPG | No Backorders Allowed.
16 | RG1608P-101-B-T5 | Susumu | RES SMD 100 OHM 0.1% 1/10W 0603 |  | 456,149 | In Stock |  | 1 | 1 | Cut Tape (CT) | RG16P100BCT-ND | 0.10000 | $0.10 | 1 | R7 | RG16P100BCT-ND | 18 | https://www.susumu.co.jp/english/product/category.php?cid=1?cid=1 |  | N/A |  | Active | ROHS3 Compliant | 1 (Unlimited) | EAR99 | 8533.21.0030 | Japan | https://www.susumu.co.jp/common/pdf/Certificate%20of%20EU%20RoHS%20compliance.pdf | RG16P100BCT-ND | https://mm.digikey.com/Volume0/opasdata/d220001/medias/images/2878/RG1005P%20SERIES.jpg
17 | RC0603FR-0747KL | YAGEO | RES 47K OHM 1% 1/10W 0603 |  | 4,028,491 | In Stock |  | 5 | 5 | Cut Tape (CT) | 311-47.0KHRCT-ND | 0.10000 | $0.50 | 1 | R9/R12/R16/R19/R22 | 311-47.0KHRCT-ND | 18 | https://www.yageogroup.com/content/datasheet/asset/file/PYU-RC_GROUP_51_ROHS_L |  | N/A |  | Active | ROHS3 Compliant | 1 (Unlimited) | EAR99 | 8533.21.0030 | Taiwan | https://www.yageo.com/en/Download/Index/certificates#rchip | 311-47.0KHRCT-ND | https://mm.digikey.com/Volume0/opasdata/d220001/medias/images/4322/cut-tape-render.jpg
18 | RMCF0603FT1K00 | Stackpole Electronics Inc | RES 1K OHM 1% 1/10W 0603 |  | 3,531,380 | In Stock |  | 3 | 3 | Cut Tape (CT) | RMCF0603FT1K00CT-ND | 0.10000 | $0.30 | 1 | R11/R13/R15 | RMCF0603FT1K00CT-ND | 17 | https://www.seielect.com/catalog/SEI-RMCF_RMCP.pdf |  | N/A |  | Active | ROHS3 Compliant | 1 (Unlimited) | EAR99 | 8533.21.0030 | Taiwan | https://www.seielect.com/catalog/SEI-RoHS_Compliance_Status.pdf|https://www.seielect.com/catalog/reach.pdf|https://www.seielect.com/catalog/sei-coc%20prop%2065.pdf | RMCF0603FT1K00CT-ND | https://mm.digikey.com/Volume0/opasdata/d220001/medias/images/4322/cut-tape-render.jpg
19 | 12065C503JAT2A | KYOCERA AVX | CAP CER 0.05UF 50V X7R 1206 |  | 5,155 | In Stock |  | 1 | 1 | Cut Tape (CT) | 478-12065C503JAT2ACT-ND | 0.13000 | $0.13 | 1 | C21 | 478-12065C503JAT2ACT-ND | 12 | https://datasheets.kyocera-avx.com/X7RDielectric.pdf |  | N/A |  | Active | ROHS3 Compliant | 1 (Unlimited) | EAR99 | 8532.24.0020 | El Salvador |  | 478-12065C503JAT2ACT-ND | https://mm.digikey.com/Volume0/opasdata/d220001/medias/images/736/1206-%283216-Metric%29-0%2C94mm-J-Code.jpg
20 | RMCF0603FT10R0 | Stackpole Electronics Inc | RES 10 OHM 1% 1/10W 0603 |  | 1,047,150 | In Stock |  | 1 | 1 | Cut Tape (CT) | RMCF0603FT10R0CT-ND | 0.10000 | $0.10 | 1 | R20 | RMCF0603FT10R0CT-ND | 17 | https://www.seielect.com/catalog/SEI-RMCF_RMCP.pdf |  | N/A |  | Active | ROHS3 Compliant | 1 (Unlimited) | EAR99 | 8533.21.0030 | Taiwan | https://www.seielect.com/catalog/SEI-RoHS_Compliance_Status.pdf|https://www.seielect.com/catalog/reach.pdf|https://www.seielect.com/catalog/sei-coc%20prop%2065.pdf | RMCF0603FT10R0CT-ND | https://mm.digikey.com/Volume0/opasdata/d220001/medias/images/4322/cut-tape-render.jpg
21 | 10TZV220M6.3X8 | Rubycon | CAP ALUM 220UF 20% 10V SMD |  | 2,198 | In Stock |  | 1 | 1 | Cut Tape (CT) | 1189-1522-1-ND | 0.52000 | $0.52 | 1 | C20 | 1189-1522-1-ND | 20 | https://www.rubycon.co.jp/wp-content/uploads/catalog-aluminum/TZV.pdf |  | N/A |  | Active | ROHS3 Compliant | 1 (Unlimited) | EAR99 | 8532.22.0020 | Japan |  | 1189-1522-1-ND | https://mm.digikey.com/Volume0/opasdata/d220001/medias/images/518/10TZV220M6.3X8.jpg
22 | LM386MX-1/NOPB | Texas Instruments | IC AMP CLASS AB MONO 325MW 8SOIC |  | 27,462 | In Stock |  | 1 | 1 | Cut Tape (CT) | LM386MX-1/NOPBCT-ND | 0.85000 | $0.85 | 1 | U5 | LM386MX-1/NOPBCT-ND | 18 | https://www.ti.com/general/docs/suppproductinfo.tsp?distId=10 |  | N/A |  | Active | ROHS3 Compliant | 1 (Unlimited) | EAR99 | 8542.33.0001 | Germany |  | LM386MX-1/NOPBCT-ND | https://mm.digikey.com/Volume0/opasdata/d220001/medias/images/6222/296%7E4040047-3%7ED%7E8.jpg
23 | P160KN-0QC20A10K | TT Electronics/BI | POT 10K OHM 1/10W PLASTIC LOG |  | 5,991 | In Stock |  | 1 | 1 | Tray | 987-1307-ND | 1.59000 | $1.59 | 1 | RV1 | 987-1307-ND | 34 | https://www.ttelectronics.com/TTElectronics/media/ProductFiles/Datasheet/P160.pdf |  | May apply on shipments to the U.S. |  | Active | ROHS3 Compliant | Not Applicable | EAR99 | 8533.40.8070 | China |  | 987-1307-ND | https://mm.digikey.com/Volume0/opasdata/d220001/medias/images/370/P160KN-0QC20A10K.jpg
24 | PTN16-A10115K1B1 | Same Sky (Formerly CUI Devices) | POT 10K OHM 1/8W CARBON LINEAR |  | 179 | In Stock |  | 1 | 1 | Tray | 2223-PTN16-A10115K1B1-ND | 1.21000 | $1.21 | 1 | RV2 | 2223-PTN16-A10115K1B1-ND | 14 | https://www.cuidevices.com/product/resource/digikeypdf/ptn16.pdf |  | May apply on shipments to the U.S. |  | Active | ROHS3 Compliant | Not Applicable | EAR99 | 8533.40.8070 | China | https://mm.digikey.com/Volume0/opasdata/d220001/medias/common/5783/ptn16-a10115k1b1.html | 2223-PTN16-A10115K1B1-ND | https://mm.digikey.com/Volume0/opasdata/d220001/medias/images/5526/MFG_PTN-16-A1.jpg
25 | AP7361C-33E-13 | Diodes Incorporated | IC REG LINEAR 3.3V 1A SOT-223-3 |  | 11,529 | In Stock |  | 1 | 1 | Cut Tape (CT) | AP7361C-33E-13DICT-ND | 0.45000 | $0.45 | 1 | U2 | AP7361C-33E-13DICT-ND | 12 | https://www.diodes.com/assets/Datasheets/AP7361C.pdf |  | N/A |  | Active | ROHS3 Compliant | 1 (Unlimited) | EAR99 | 8542.39.0090 | China | https://mm.digikey.com/Volume0/opasdata/d220001/medias/docus/6731/Diode%20RoHS3%20REACH%20247%20Jan%202025%20Statement.pdf | AP7361C-33E-13DICT-ND | https://mm.digikey.com/Volume0/opasdata/d220001/medias/images/4895/31%7ESOT223%7EE%2CG%2CH%7E4.JPG
26 | LMK316B7475MLHT | Taiyo Yuden | CAP CER 4.7UF 10V X7R 1206 |  | 917 | In Stock |  | 2 | 2 | Cut Tape (CT) | 587-LMK316B7475MLHTCT-ND | 0.31000 | $0.62 | 1 | C7/C8 | 587-LMK316B7475MLHTCT-ND | 11 | https://mm.digikey.com/Volume0/opasdata/d220001/medias/docus/2307/LMK316B7475MLHT_SS.pdf |  | N/A |  | Active | ROHS3 Compliant | 1 (Unlimited) | EAR99 | 8532.24.0020 | South Korea |  | 587-LMK316B7475MLHTCT-ND | https://mm.digikey.com/Volume0/opasdata/d220001/medias/images/2600/M%20Series%201206%20%28Thick%201.90%29.jpg
27 | CRG0603F330R | TE Connectivity Passive Product | RES SMD 330 OHM 1% 1/10W 0603 |  | 724,813 | In Stock |  | 1 | 1 | Cut Tape (CT) | A121525CT-ND | 0.10000 | $0.10 | 1 | R5 | A121525CT-ND | 14 | https://www.te.com/commerce/DocumentDelivery/DDEController?Action=srchrtrv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 |  | N/A |  | Active | ROHS3 Compliant | 1 (Unlimited) | EAR99 | 8533.21.0030 | Thailand | http://www.te.com/commerce/alt/SinglePartSearch.do?PN=1622918-1&dest=stmt | A121525CT-ND | https://mm.digikey.com/Volume0/opasdata/d220001/medias/images/2530/CRG%2C%20Neohm%200603%20%281608%20Metric%29.jpg
28 | 3220-10-0100-00 | CNC Tech | CONN HEADER VERT 10POS 1.27MM |  | 217,310 | In Stock |  | 1 | 1 | Tray | 1175-1627-ND | 0.64000 | $0.64 | 1 | J4 | 1175-1627-ND | 20 | http://www.cnctech.us/pdfs/3220-XX-0100-00_.pdf |  | N/A |  | Active | ROHS3 Compliant | Non-JEDEC | EAR99 | 8536.69.4040 | Taiwan | https://www.cnctech.us/REACH%20235%20and%20RoHS%20declaration%2010-2023.pdf | 1175-1627-ND | https://mm.digikey.com/Volume0/opasdata/d220001/medias/images/663/3220-10-0100-00.JPG
29 | B2B-PH-K-S | JST Sales America Inc. | CONN HEADER VERT 2POS 2MM |  | 128,575 | In Stock |  | 1 | 1 | Bulk | 455-1704-ND | 0.10000 | $0.10 | 1 | LS1 | 455-1704-ND | 16 | https://www.jst-mfg.com/product/pdf/eng/ePH.pdf |  | N/A |  | Active | ROHS3 Compliant | 1 (Unlimited) | EAR99 | 8536.69.4040 | Malaysia |  | 455-1704-ND | https://mm.digikey.com/Volume0/opasdata/d220001/medias/images/1081/B2B-PH-K-S.jpg
30 | C3900BA | Bulgin | SWITCH TOGGLE SPST 20A 125V |  | 7,352 | In Stock |  | 1 | 1 | Bulk | 1091-1026-ND | 10.56000 | $10.56 | 1 | SW1 | 1091-1026-ND | 23 | https://www.bulgin.com/products/pub/media/bulgin/data/A_Toggle%20Switch.pdf |  | N/A |  | Active | ROHS3 Compliant | 1 (Unlimited) | EAR99 | 8536.50.9065 | China | https://www.bulgin.com/en/products/pub/media/import/attachments/RoHS.pdf|https://www.bulgin.com/en/products/pub/media/import/attachments/REACH.pdf | 1091-1026-ND | https://mm.digikey.com/Volume0/opasdata/d220001/medias/images/378/C3900BA.jpg
31 | ESP32-WROOM-32E-N8R2 | Espressif Systems | RF TXRX MOD BT WIFI PCB TH SMD |  | 4,742 | In Stock |  | 1 | 1 | Cut Tape (CT) | 5407-ESP32-WROOM-32E-N8R2CT-ND | 5.38000 | $5.38 | 1 | U6 | 5407-ESP32-WROOM-32E-N8R2CT-ND | 8 | https://www.espressif.com/sites/default/files/documentation/esp32-wroom-32e_esp32-wroom-32ue_datasheet_en.pdf |  | May apply on shipments to the U.S. |  | Active | Unknown | 3 (168 Hours) | 5A992C SC | 8517.62.0090 | China |  | 5407-ESP32-WROOM-32E-N8R2CT-ND | https://mm.digikey.com/Volume0/opasdata/d220001/derivates/6/003/223/719/ESP32-WROOM-32E-N8R2_web%28640x640%29.jpg
32 | DX07S016JA1R1500 | JAE Electronics | CONN RCP USB2.0 TYP C 24P SMD RA |  | 17,119 | In Stock |  | 1 | 1 | Cut Tape (CT) | 670-DX07S016JA1R1500CT-ND | 1.67000 | $1.67 | 1 | J5 | 670-DX07S016JA1R1500TR-ND | 15 | https://mm.digikey.com/Volume0/opasdata/d220001/medias/docus/7162/670_DX07S016JA1R1500.pdf |  | May apply on shipments to the U.S. |  | Active | ROHS3 Compliant | 1 (Unlimited) | EAR99 | 8536.69.4040 | China |  | 670-DX07S016JA1R1500TR-ND | https://mm.digikey.com/Volume0/opasdata/d220001/medias/images/3768/MFG_DX07S016JA1R1500.jpg
33 | CP2102N-A02-GQFN24 | Silicon Labs | IC USB TO UART BRIDGE QFN24 |  | 2,795 | In Stock |  | 1 | 1 | Tube | 336-5887-ND | 4.14000 | $4.14 | 1 | U7 | 336-5887-ND | 20 | https://www.silabs.com/documents/public/data-sheets/cp2102n-datasheet.pdf |  | N/A |  | Active | ROHS3 Compliant | 2 (1 Year) | EAR99 | 8542.39.0070 | China |  | 336-5887-ND
34 | ESD122DMYR | Texas Instruments | TVS DIODE 3.6VWM 8.4VC 3X2SON |  | 23,379 | In Stock |  | 1 | 1 | Cut Tape (CT) | 296-47120-1-ND | 0.99000 | $0.99 | 1 | D2 | 296-47120-2-ND | 6 | https://www.ti.com/general/docs/suppproductinfo.tsp?distId=10 |  | May apply on shipments to the U.S. |  | Active | ROHS3 Compliant | 1 (Unlimited) | EAR99 | 8541.10.0080 | China |  | 296-47120-2-ND | https://mm.digikey.com/Volume0/opasdata/d220001/medias/images/2309/MFG_ESD122DMYR.jpg
35 | RMCF0603FT10R0 | Stackpole Electronics Inc | RES 10 OHM 1% 1/10W 0603 |  | 1,047,150 | In Stock |  | 1 | 1 | Cut Tape (CT) | RMCF0603FT10R0CT-ND | 0.10000 | $0.10 | 1 | R14 | RMCF0603FT10R0CT-ND | 17 | https://www.seielect.com/catalog/SEI-RMCF_RMCP.pdf |  | N/A |  | Active | ROHS3 Compliant | 1 (Unlimited) | EAR99 | 8533.21.0030 | Taiwan | https://www.seielect.com/catalog/SEI-RoHS_Compliance_Status.pdf|https://www.seielect.com/catalog/reach.pdf|https://www.seielect.com/catalog/sei-coc%20prop%2065.pdf | RMCF0603FT10R0CT-ND | https://mm.digikey.com/Volume0/opasdata/d220001/medias/images/4322/cut-tape-render.jpg
36 | RMCF0603FT5K10 | Stackpole Electronics Inc | RES 5.1K OHM 1% 1/10W 0603 |  | 308,663 | In Stock |  | 2 | 2 | Cut Tape (CT) | RMCF0603FT5K10CT-ND | 0.10000 | $0.20 | 1 | R16/R17 | RMCF0603FT5K10CT-ND | 17 | https://www.seielect.com/catalog/SEI-RMCF_RMCP.pdf |  | N/A |  | Active | ROHS3 Compliant | 1 (Unlimited) | EAR99 | 8533.21.0030 | Taiwan | https://www.seielect.com/catalog/SEI-RoHS_Compliance_Status.pdf|https://www.seielect.com/catalog/reach.pdf|https://www.seielect.com/catalog/sei-coc%20prop%2065.pdf | RMCF0603FT5K10CT-ND | https://mm.digikey.com/Volume0/opasdata/d220001/medias/images/4849/738_0603.jpg
37 | RMCF0603FT22R0 | Stackpole Electronics Inc | RES 22 OHM 1% 1/10W 0603 |  | 2,969,553 | In Stock |  | 2 | 2 | Cut Tape (CT) | RMCF0603FT22R0CT-ND | 0.10000 | $0.20 | 1 | R18/R19 | RMCF0603FT22R0CT-ND | 17 | https://www.seielect.com/catalog/SEI-RMCF_RMCP.pdf |  | May apply on shipments to the U.S. |  | Active | ROHS3 Compliant | 1 (Unlimited) | EAR99 | 8533.21.0030 | China | https://www.seielect.com/catalog/SEI-RoHS_Compliance_Status.pdf|https://www.seielect.com/catalog/reach.pdf|https://www.seielect.com/catalog/sei-coc%20prop%2065.pdf | RMCF0603FT22R0CT-ND | https://mm.digikey.com/Volume0/opasdata/d220001/medias/images/4849/738_0603.jpg
38 | B6PS-VH | JST Sales America Inc. | CONN HEADER R/A 6POS 3.96MM |  | 4,808 | In Stock |  | 1 | 1 | Bulk | 455-B6PS-VH-ND | 0.35000 | $0.35 | 1 | J2 | 455-B6PS-VH-ND | 16 | https://www.jst-mfg.com/product/pdf/eng/eVH.pdf |  | N/A |  | Active | ROHS3 Compliant | 1 (Unlimited) | EAR99 | 8536.69.4040 | Malaysia |  | 455-B6PS-VH-ND | https://mm.digikey.com/Volume0/opasdata/d220001/medias/images/1104/B6PS-VH.jpg
39 | B4PS-VH | JST Sales America Inc. | CONN HEADER R/A 4POS 3.96MM |  | 8,692 | In Stock |  | 1 | 1 | Bulk | 455-B4PS-VH-ND | 0.25000 | $0.25 | 1 | J3 | 455-B4PS-VH-ND | 16 | https://www.jst-mfg.com/product/pdf/eng/eVH.pdf |  | N/A |  | Active | ROHS3 Compliant | 1 (Unlimited) | EAR99 | 8536.69.4040 | Malaysia |  | 455-B4PS-VH-ND | https://mm.digikey.com/Volume0/opasdata/d220001/medias/images/1110/B4PS-VH.jpg
40 | VHR-6M | JST Sales America Inc. | CONN RCPT HSG 6POS 3.96MM |  | 984 | In Stock |  | 1 | 1 | Bulk | 455-3984-ND | 0.24000 | $0.24 | 1 |  | 455-3984-ND | 16 | https://www.jst-mfg.com/product/pdf/eng/eVH.pdf |  | N/A |  | Active | ROHS3 Compliant | 1 (Unlimited) | EAR99 | 8538.90.6000 | Japan |  | 455-3984-ND | https://mm.digikey.com/Volume0/opasdata/d220001/medias/images/1144/VHR-6N.jpg
41 | VHR-4N | JST Sales America Inc. | CONN RCPT HSG 4POS 3.96MM |  | 19,332 | In Stock |  | 1 | 1 | Bulk | 455-1185-ND | 0.11000 | $0.11 | 1 |  | 455-1185-ND | 16 | https://www.jst-mfg.com/product/pdf/eng/eVH.pdf |  | N/A |  | Active | ROHS3 Compliant | 1 (Unlimited) | EAR99 | 8538.90.6000 | Malaysia |  | 455-1185-ND | https://mm.digikey.com/Volume0/opasdata/d220001/medias/images/1040/VHR-4N.jpg

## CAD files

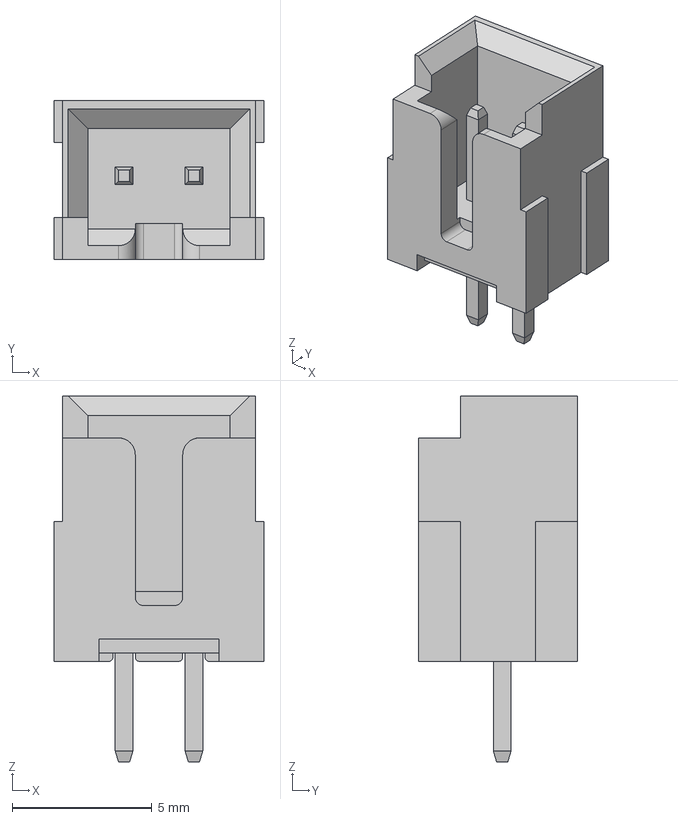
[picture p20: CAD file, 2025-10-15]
board/3d-models/audio-speaker-connector.step
7.50 x 5.70 x 13.1 mm

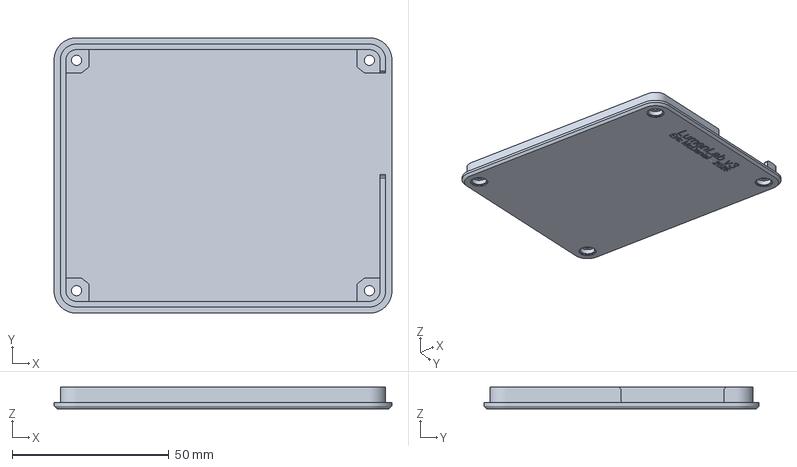
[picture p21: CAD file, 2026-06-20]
board/enclosure/v3/lumenlab-platform-enclosure-v3-lid.3mf
107.9 x 87.9 x 7.00 mm

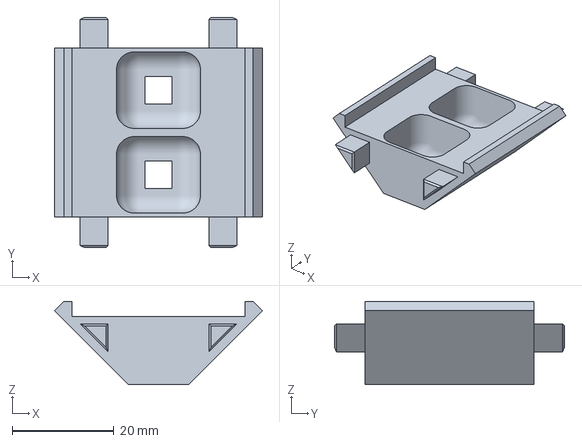
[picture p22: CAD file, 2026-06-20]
board/mount/v3/led-strip-v3-bracket-mirrored_2__dark.3mf
40.9 x 45.3 x 16.4 mm

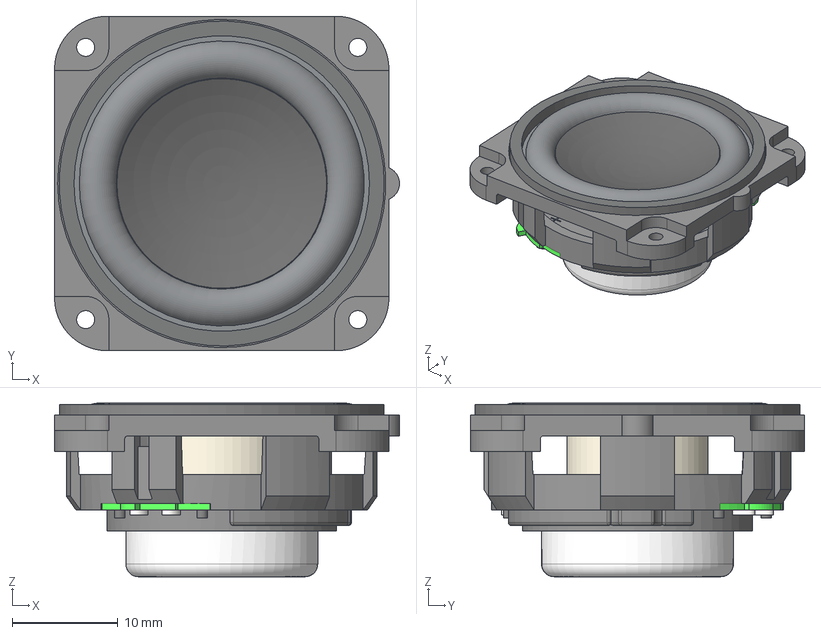
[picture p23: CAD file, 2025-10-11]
board/3d-models/Speaker.step
32.7 x 31.7 x 16.4 mm

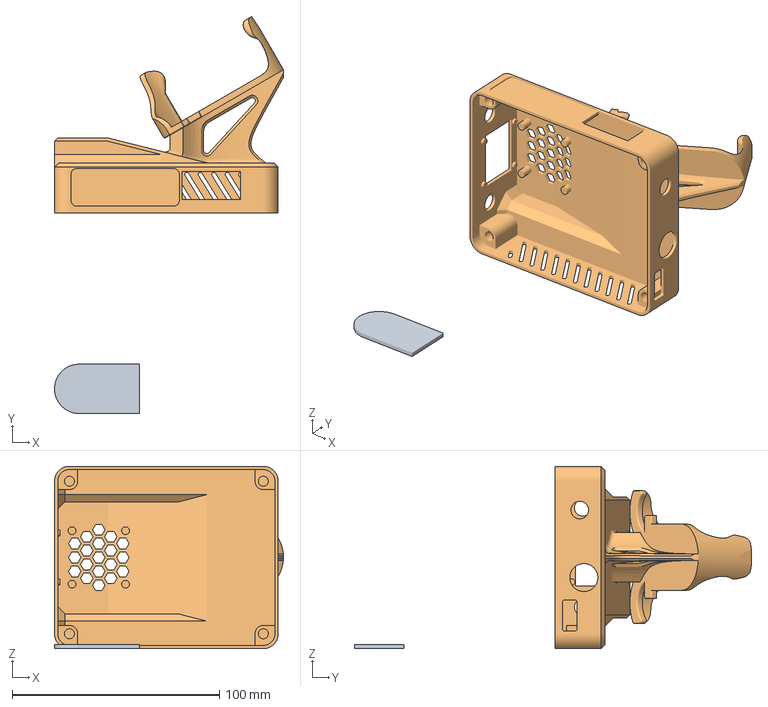
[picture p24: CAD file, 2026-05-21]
board/enclosure/v3/lumenlab-platform-enclosure-v3-body-with-controller-saddle.3mf
110.4 x 191.4 x 87.9 mm
lumenlab-platform-enclosure-v3-body-with-controller-saddle-accessories-minimal

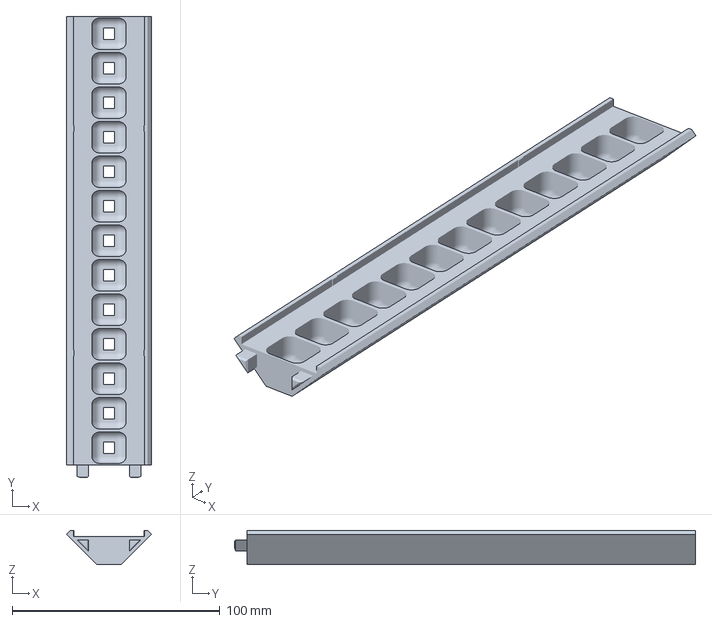
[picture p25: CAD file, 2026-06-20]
board/mount/v3/led-strip-v3-bracket-only__dark.3mf
40.9 x 221.7 x 16.4 mm

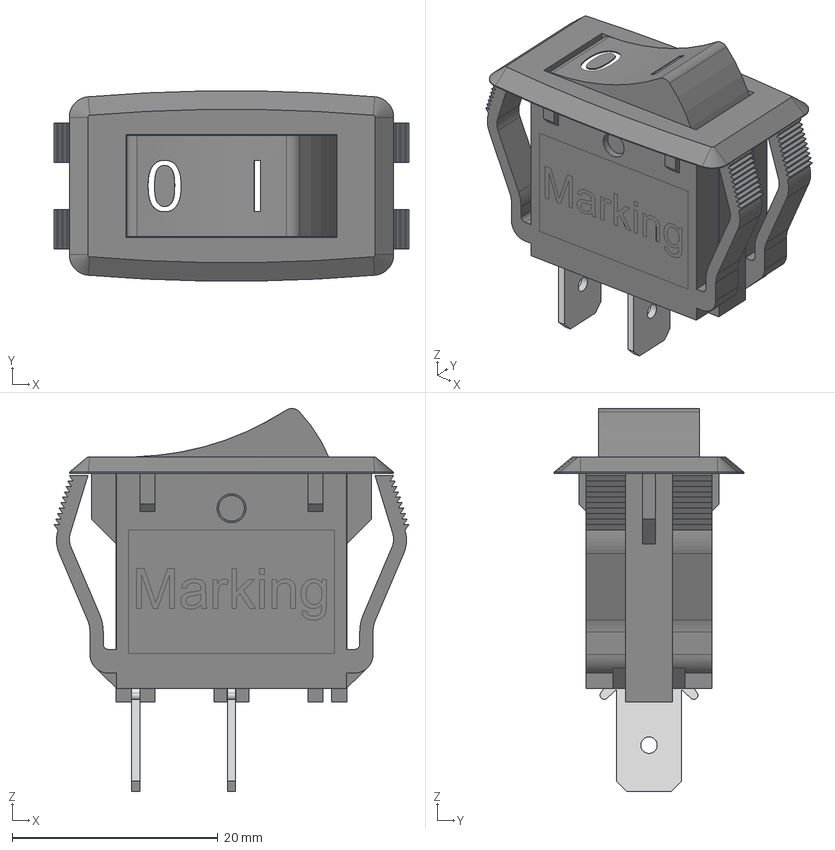
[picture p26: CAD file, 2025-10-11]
board/3d-models/RockerPowerSwitch.step
34.5 x 18.5 x 37.2 mm
Frame
Actuator
Terminal x 2

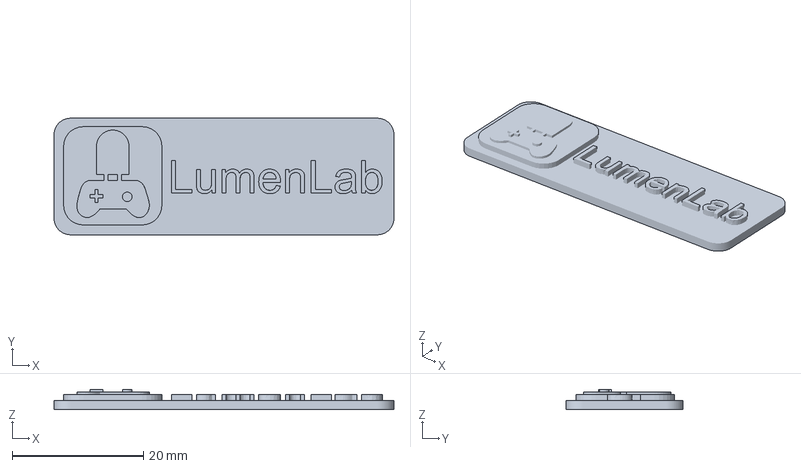
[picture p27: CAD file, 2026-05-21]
board/enclosure/v3/lumenlab-platform-enclosure-branding.3mf
51.9 x 17.8 x 3.10 mm

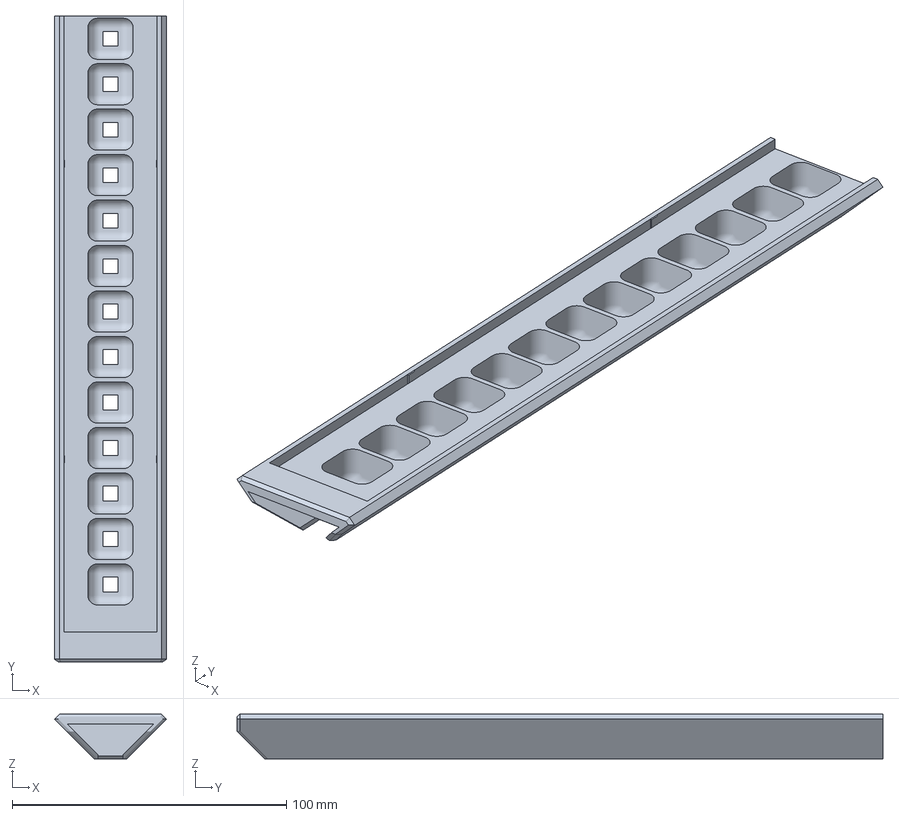
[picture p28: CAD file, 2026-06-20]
board/mount/v3/led-strip-v3-left-bracket-w-endcap__dark.3mf
40.9 x 235.7 x 16.4 mm

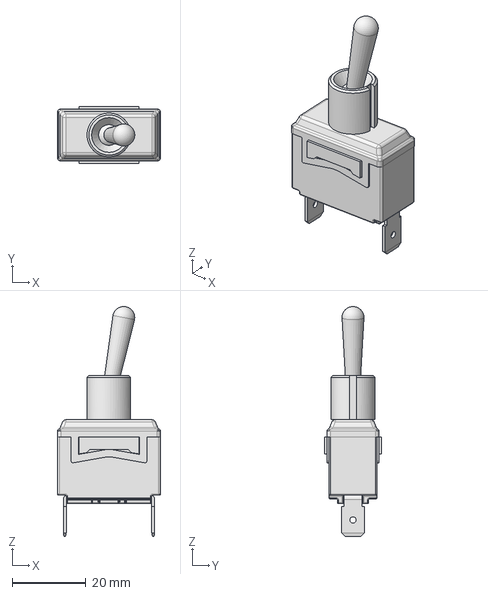
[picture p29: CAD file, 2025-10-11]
board/3d-models/ST141D00.step
28.0 x 15.5 x 62.4 mm

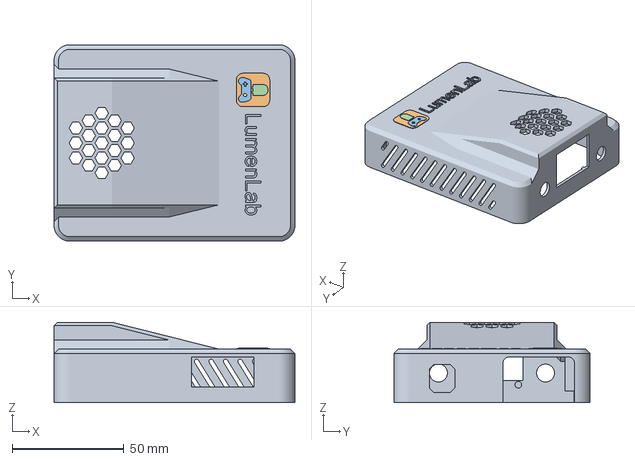
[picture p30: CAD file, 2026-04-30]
board/enclosure/v3/lumenlab-platform-enclosure-v3-body-no-controller-saddle.3mf
107.9 x 87.9 x 36.0 mm

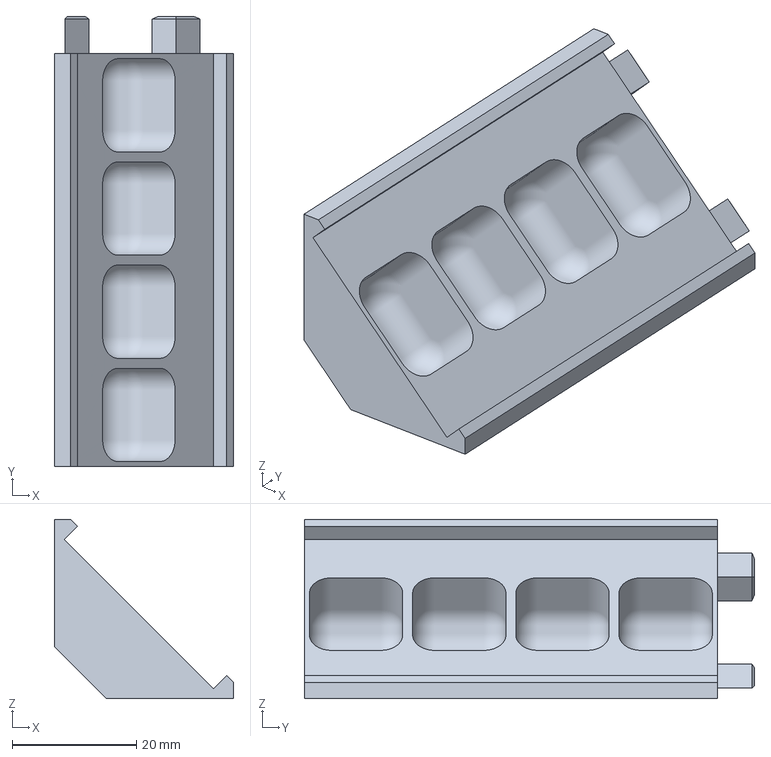
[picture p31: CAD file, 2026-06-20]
board/mount/v3/led-strip-v3-bracket-mirrored__dark.3mf
28.9 x 72.5 x 28.9 mm

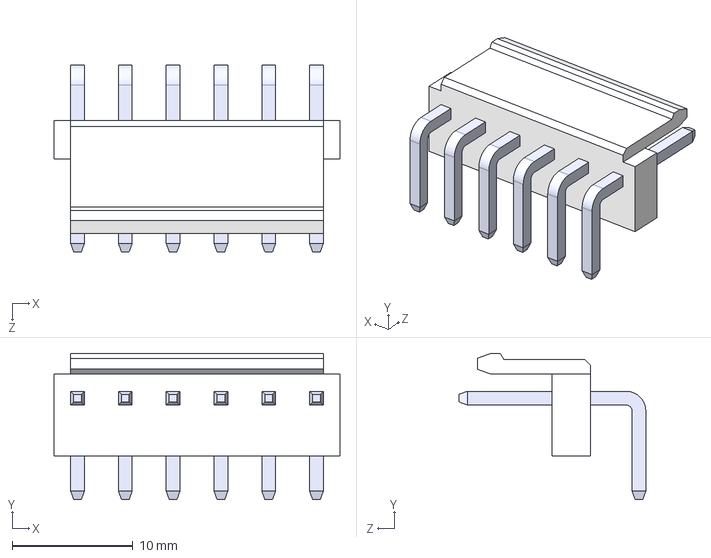
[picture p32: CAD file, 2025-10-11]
board/3d-models/B6PS-VH-jst-vh-connector.step
23.7 x 12.1 x 15.5 mm
BxPS-VH_6
pin^BxPS-VH ass x 6

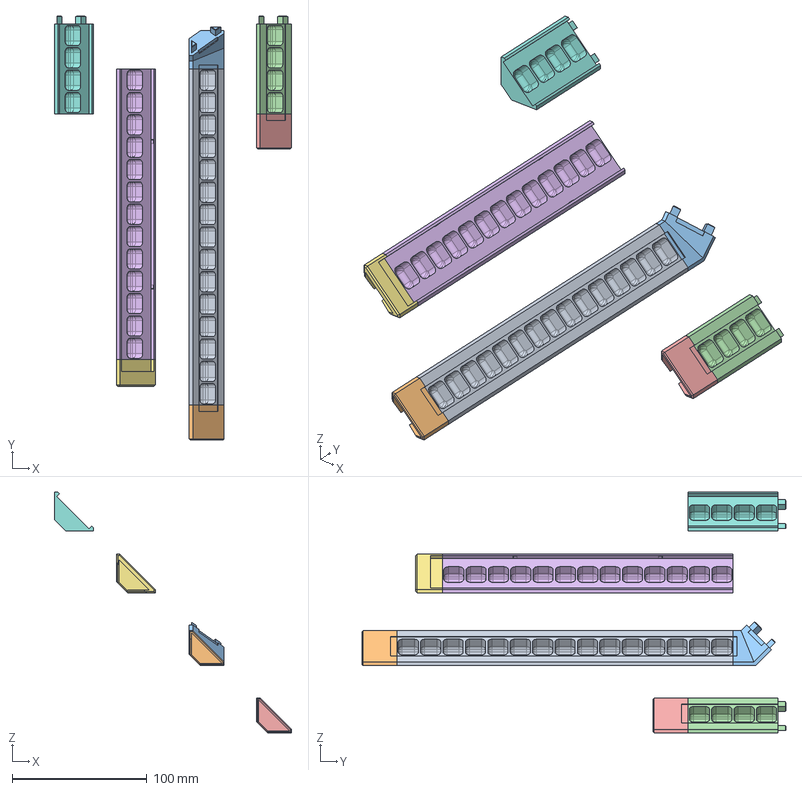
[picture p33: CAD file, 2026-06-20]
board/mount/v3/led-strip-mount-and-bracket-v3.FCStd
176.0 x 314.7 x 178.9 mm
bracket-standard
endcap-left-standard
endcap-joint-standard
bracket-mirrored-standard
endcap-left-standard-clone
bracket-variant
endcap-left-variant
bracket-mirrored-variant

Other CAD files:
board/3d-models/0ZRE0005FF1C.stp
board/mount/v3/led-strip-v3-bracket-only-mounting-guide.3mf
board/3d-models/CP2102N-A02-GQFN24R.step
board/mount/v3/led-strip-v3-right-bracket-w-endcap__dark.3mf
board/3d-models/10TZV220M6-speaker-cap.step
board/3d-models/1264EY-6R8M_P3-inductor.step
board/3d-models/16SEPF1000M.step
board/3d-models/504-nav-switch.stp
board/3d-models/B2B-PH-K-S.step
board/3d-models/B4PS-VH-jst-vh-connector.step
board/3d-models/BarrelJack.step
board/3d-models/EMZS250ARA102MJA0G-led-decoupling-cap.step
board/3d-models/ESD122DMYR.step
board/3d-models/FTSH-105-01-S-DV-TR.step
board/3d-models/JTAG-header.STEP
board/3d-models/LM386MX-1_NOPB.step
board/3d-models/MP2338.step
board/3d-models/SMAJ12CA-tvs-diode.step
board/3d-models/SN74AHCT1G125DBVR.step
board/3d-models/SN74HC14DR.step
board/3d-models/SSD1306.step
board/3d-models/USB-C.step
board/3d-models/potentiometer.step
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

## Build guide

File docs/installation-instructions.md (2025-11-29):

# Installation Instructions

This guide explains how to flash the **LumenLab firmware** to your ESP32 using **Windows PowerShell**.
The process is fully automated using a single one-line command.

---

## Quick Install (One-Line PowerShell Command)

The installation script assumes you have Docker Desktop and WSL2 installed in advance and running. If you don't, download them first before proceeding.

> **Open PowerShell as Administrator**, then run:

```powershell
Set-ExecutionPolicy Bypass -Scope Process -Force; `iwr -useb https://raw.githubusercontent.com/ericmcdaniel/lumenlab/refs/heads/main/tools/install-lumenlab.ps1`
| iex
```

This command:

- Downloads the installation script
- Detects your ESP32
- Handles USB passthrough to WSL
- Pulls the latest Docker image
- Flashes the firmware automatically

---

## Troubleshooting

### “Timeout waiting for /dev/ttyUSB0”
- Ensure the ESP32 is physically plugged in
- Try a different USB cable (must support **data**, not just charging)
- Try unplugging and reconnecting the ESP32

---

### "usbipd : The term 'usbipd' is not recognized as the name of a cmdlet"
The script requires usbipd to be installed. This should have been included in your WSL2 installation, but if not you can install it manually.
```powershell
winget install --exact dorssel.usbipd-win
```

Then re-run the install command.

---

### “usbipd: error: Device is already attached”
The script attempts to resolve this automatically.
To manually reset device attachments:

```powershell
usbipd detach --all
```

Then re-run the install command.

---

### Docker error: “WSL integration disabled”
Open Docker Desktop, and enable it under:

> Docker Desktop → Settings → Resources → WSL Integration → Enable Ubuntu

---

## How to Verify Successful Flash

Assuming everything worked:
- The ESP32 will reboot
- The LumenLab logo should appear on the screen
- Red LED animations may begin if you don't connect your PS3 controller within 30 seconds

---

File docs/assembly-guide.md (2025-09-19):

# Assembly Guide

The LumenLab can be physically assembled using two different methods. The first is a DIY approach, which involves manually soldering the through-hole components and ICs on to a perfboard. The other is to take the KiCad generated Gerber file and have the PCB professionally manufactured. With that option you can have the manufacturer assemble the board for you at additional cost, or you can purchase the stencil and reflow the parts on directly.

This guide's intention is to identity what components and ICs are required for both options if you want to create the LumenLab as well.

## Perfboard Prototype with Through-hole Components

Review the table listed on the [Perfboard Prototype Component Selection](prototype-component-selection.md) guide. These components are functionally equivalent (for the most part) to the SMT parts used in the manufactured version, however they typically are in the through-hole package where available for easy soldering. The one main exception is the buck converter module, MP1584. I used a off-the-shelf module for simplicity when prototyping. The main downside is that there is no package of that module available in a perfboard/breadboard friendly format, such as TO-220. The version listed in the table can instead be soldered to header pins, which I then soldered to the perfboard.

## SMT PCB Professionally Manufactured

This is currently being designed, so I don't have guidance on this yet.

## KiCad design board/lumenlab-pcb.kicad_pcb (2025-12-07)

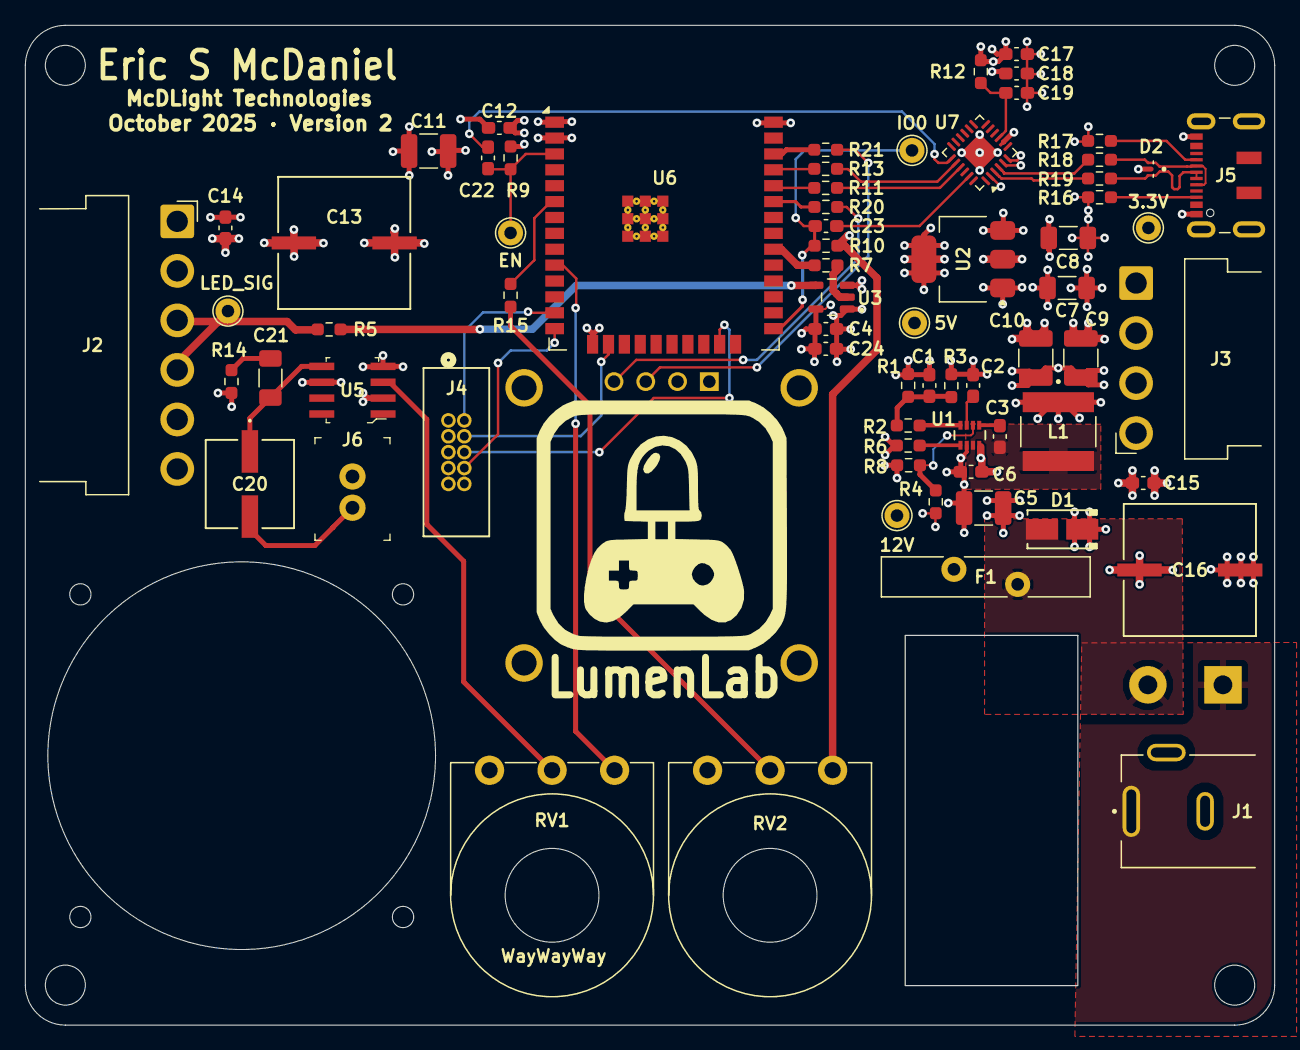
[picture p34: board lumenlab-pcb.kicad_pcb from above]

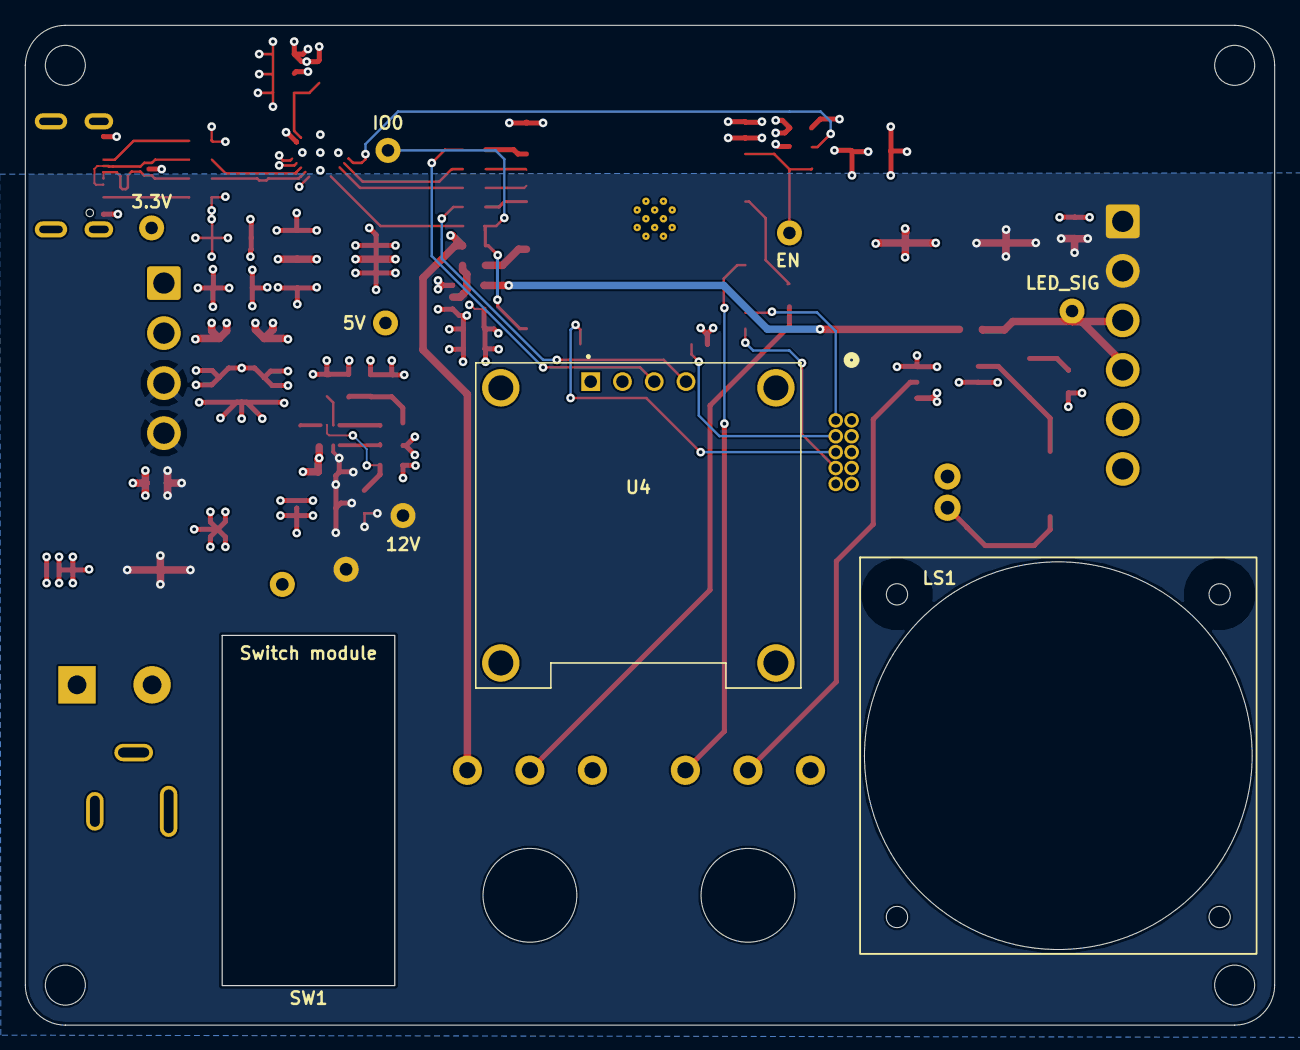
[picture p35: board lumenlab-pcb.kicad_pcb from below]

Board: 4 copper layers, 99.9 x 79.9 mm, 76 parts (3 on the bottom side), 47 nets.

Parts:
C1: 300pF; C_0603_1608Metric_Pad1.08x0.95mm_HandSolder
C2: 22nF; C_0603_1608Metric_Pad1.08x0.95mm_HandSolder
C3, C4, C6, C12, C14, C15, C17, C18, C19, C22, C23, C24: 0.1uF; C_0603_1608Metric_Pad1.08x0.95mm_HandSolder
C5, C9, C10, C11: 22uF; C_1210_3225Metric_Pad1.33x2.70mm_HandSolder
C7, C8: 4.7uF; C_1206_3216Metric_Pad1.33x1.80mm_HandSolder
C13, C16: 1000uF; CAP_JA0_NIP
C20: 250uF; CAP_J-V_6P3X8_RUB-M
C21: 0.05uF; C_1206_3216Metric_Pad1.33x1.80mm_HandSolder
D1: SMAJ12CA; SMASeries_LTF-M
D2: ESD122DMYR; DIO_ESD122DMYR
F1: Polyfuse; Fuse_Bourns_MF-RG1000
H1, H2, H3, H4: MountingHole; MountingHole_3.2mm_M3
J1: 2.1mm Barrel Jack; 2_Vendor_BarrelJack
J2: 01x06; JST_VH_1x06_P3.96_SilkscreenTrimmed
J3: 01x04; JST_VH_1x04_P3.96mm_SilkscreenTrimmed
J4: JTAG; JTAG-header
J5: USB_C_Receptacle_USB2.0_16P; USB_C_Receptacle_JAE_DX07S016JA1R1500
J6: B2B-XH-A_LF__SN_; PinHeader_1x2_P2.5mm_Drill1.1mm
L1: 6.8uH; IND_1264EY-6R8M=P3
LS1: Speaker
R1: 90.9K; R_0603_1608Metric_Pad0.98x0.95mm_HandSolder
R2, R3, R6, R9, R10, R12: 10K; R_0603_1608Metric_Pad0.98x0.95mm_HandSolder
R4: 191K; R_0603_1608Metric_Pad0.98x0.95mm_HandSolder
R5: 330; R_0603_1608Metric_Pad0.98x0.95mm_HandSolder
R7: 33; R_0603_1608Metric_Pad0.98x0.95mm_HandSolder
R8: 49.9K; R_0603_1608Metric_Pad0.98x0.95mm_HandSolder
R11, R13, R15: 1K; R_0603_1608Metric_Pad0.98x0.95mm_HandSolder
R14: 10; R_0603_1608Metric_Pad0.98x0.95mm_HandSolder
R16, R17: 5.1K; R_0603_1608Metric_Pad0.98x0.95mm_HandSolder
R18, R19: 22; R_0603_1608Metric_Pad0.98x0.95mm_HandSolder
R20, R21: 4.7K; R_0603_1608Metric_Pad0.98x0.95mm_HandSolder
RV1: 10K LOG; Potentiometer
RV2: 10K LIN; Potentiometer
SW1: SW_SPST; RockerPowerSwitch
TP1: 12V; TestPoint_THTPad_D2.0mm_Drill1.0mm
TP2: EN; TestPoint_THTPad_D2.0mm_Drill1.0mm
TP3: IO0; TestPoint_THTPad_D2.0mm_Drill1.0mm
TP4: 3.3V; TestPoint_THTPad_D2.0mm_Drill1.0mm
TP5: 5V; TestPoint_THTPad_D2.0mm_Drill1.0mm
TP6: LED_SIG; TestPoint_THTPad_D2.0mm_Drill1.0mm
U1: MP2338; MP2338_MNP-M
U2: AP7361C-33E; SOT-223-3_TabPin2
U3: SN74AHCT1G125; SOT95P280X145-5N
U4: SSD1306; SSD1306_OLED_MODULE
U5: LM386MX; SOIC-8_W3.9mm
U6: ESP32-WROOM-32E; ESP32_WROOM_32E
U7: CP2102N-Axx-xQFN24; QFN-24-1EP_4x4mm_P0.5mm_EP2.15x2.15mm

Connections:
+3.3V: C8.1, C11.2, C12.1, C17.1, C18.1, R9.1, R10.1, R12.2, RV2.3, TP4.1, U2.3 (VO), U6.2 (VDD), U7.5 (VIO), U7.6 (VDD)
+5V: C1.2, C4.2, C7.1, C9.1, C10.1, C24.1, J4.1, L1.1, R1.2, R6.2, TP5.1, U2.1 (VI), U3.5 (VCC), U4.2 (VCC), U5.6, U7.8 (VBUS)
+12V: C5.1, C6.1, C13.1, C14.1, C15.1, C16.1, F1.2, J2.1, J2.2, J3.3, J3.4, R4.1, TP1.1, U1.2 (VIN)
/AMP_IN: RV1.2, U5.3
/BUCK_BST: C3.1, U1.5 (BST)
/BUCK_EN: R4.2, R8.1, U1.6 (EN)
/BUCK_FB: R2.1, U1.8 (FB)
/BUCK_PG: R6.1, U1.1 (PG)
/BUCK_SS: C2.2, U1.7 (SS)
/BUCK_SW: C3.2, L1.2, U1.3 (SW)
/DATA+: R19.2, U7.3 (D+)
/DATA-: R18.2, U7.4 (D-)
/ESP32_EN: C22.2, R9.2, TP2.1, U6.3 (EN)
/ESP32_GPIO0: C23.2, R10.2, TP3.1, U6.25 (IO0)
/ESP32_GPIO12: J4.8, U6.14 (IO12)
/ESP32_GPIO13: J4.4, U6.16 (IO13)
/ESP32_GPIO14: J4.2, U6.13 (IO14)
/ESP32_GPIO15: J4.6, U6.23 (IO15)
/ESP32_GPIO18: R7.2, U6.30 (IO18)
/ESP32_GPIO21: R20.1, U6.33 (IO21)
/ESP32_GPIO22: R21.1, U6.36 (IO22)
/ESP32_GPIO25: RV1.3, U6.10 (IO25)
/ESP32_GPIO34: R15.2, U6.6 (IO34)
/ESP32_RX: R11.2, U6.34 (RXD0/IO3)
/ESP32_TX: R13.2, U6.35 (TXD0/IO1)
/FUSE: D1.2, F1.1, SW1.2 (B)
/LED_DIN: J2.3, J2.4, R5.2, TP6.1
/USB_D+: D2.3, J5.A6 (D+), J5.B6 (D+), R19.1
/USB_D-: D2.2, J5.A7 (D-), J5.B7 (D-), R18.1
GND: C2.1, C4.1, C5.2, C6.2, C7.2, C8.2, C9.2, C10.2, C11.1, C12.2, C13.2, C14.2, C15.2, C16.2, C17.2, C18.2, C19.2, C24.2, D1.1, D2.1, J1.2, J1.3, J2.5, J2.6, J3.1, J3.2, J4.3, J4.5, J4.7, J4.9, J5.A1 (GND), J5.A12 (GND), J5.B1 (GND), J5.B12 (GND), J6.2, R3.2, R8.2, R14.1, R16.2, R17.2, RV1.1, RV2.1, U1.4 (GND), U2.2 (GND), U3.1 (~OE), U3.3 (GND), U4.1 (GND), U5.2, U5.4, U6.1 (GND), U6.15 (GND), U6.38 (GND), U6.39 (GND), U7.2 (GND), U7.25 (GND)
unnamed: C1.1, R1.1, R2.2, R3.1
unnamed: C20.1, C21.1, U5.5
unnamed: C20.2, J6.1
unnamed: C21.2, R14.2
unnamed: J5.A5 (CC1), R16.1
unnamed: J5.B5 (CC2), R17.1
unnamed: R15.1, RV2.2
unnamed: J1.1, SW1.1 (A)
unnamed: R7.1, U3.2 (A)
unnamed: R5.1, U3.4 (Y)
unnamed: R21.2, U4.3 (SCL)
unnamed: R20.2, U4.4 (SDA)
unnamed: R13.1, U7.20 (RXD)
unnamed: R11.1, U7.21 (TXD)
unnamed: C23.1, U7.23 (~DTR)
unnamed: C19.1, R12.1, U7.9 (~RST)
unnamed: C22.1, U7.19 (~RTS)

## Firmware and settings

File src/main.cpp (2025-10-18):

#include <Arduino.h>
#include "engine/engine.h"

void setup()
{
  Engine::GameEngine engine;
  engine.runApplication();
}

/**
 * loop() functions just as a catch block does in modern try/catch exception handling.
 * There is no game logic here, only the strip oscillating on and off in red.
 */
void loop()
{
  Serial.println("LumenLab has encountered an unrecoverable error state.");
  delay(1000);
}

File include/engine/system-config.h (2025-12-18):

#pragma once

#include <cstdint>

namespace Engine
{
  struct SystemConfig
  {
    // REQUIRED: modify this address to match the mac address of your PS3 controller
    static constexpr char macAddress[] = "00:1b:fb:8e:87:ac";
    static constexpr uint16_t numLeds = 327;
    static constexpr uint32_t serialBaud = 921600;
    static constexpr uint16_t recallBoundaries[4] = {0, 113, 168, 281};
    static constexpr uint8_t ledDimmerGpio = 34;
  };
}

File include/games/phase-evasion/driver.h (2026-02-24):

#pragma once

#include "engine/layer.h"
#include "engine/timer.h"
#include "core/context-manager.h"
#include "games/phase-evasion/player.h"
#include "games/phase-evasion/flare.h"
#include "games/phase-evasion/flare-manager.h"
#include "games/phase-evasion/gem.h"

namespace Games::PhaseEvasion
{
  class Driver : public Engine::Layer, private Engine::Timer
  {
  public:
    Driver(SystemCore::ContextManager *ctx);
    ~Driver() { state.reset(); }
    void nextEvent() override;
    static constexpr uint16_t playerOffset = 25;
    static constexpr uint16_t playerWidth = 5;
    static constexpr uint32_t windDownLength = 20'000;

  private:
    SystemCore::ContextManager *contextManager;
    GameState &state;

    Player player;
    FlareManager flareManager;
    Gem gem;

    Engine::Timer windDownTimer;
    Engine::Timer gemTimeoutTimer;

    float interval;
    float gap;
    float speed;

    uint32_t gemRespawnDelay = 5000;
    uint32_t gemCaptureDelay = 15000;

    float gameOverPhaseShift = 0.0f;
    float gameOverPhaseOffset = 0.0f;

    void getUpdates();
    void checkIfHighScore();
    void renderPlayer();
    void renderFlare();
    void renderGem();
    void checkCollision();
    void checkGemCapture();
    void assessDifficulty();
    void muzzleFlash();
    void gameOver();
    void reset();
  };
}

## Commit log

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2025-08-12 Replace sockets with USB Serial
    [main.cpp]
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2025-09-01 Add basic power supply
    [lumenlab-pcb.kicad_pcb, lumenlab-pcb.kicad_sch]
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2025-09-01 Finish buck converter schematic
    [lumenlab-pcb.kicad_pcb, lumenlab-pcb.kicad_sch]
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2025-09-05 Fix mislabeled netlist
    [lumenlab-pcb.kicad_pcb, lumenlab-pcb.kicad_sch]
2025-09-05 Add ESP32 to schematic
    [lumenlab-pcb.kicad_pcb, lumenlab-pcb.kicad_sch]
2025-09-06 Replace AMS1117 with AP7361C
    [lumenlab-pcb.kicad_sch]
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2025-09-12 Fix incorrect bias of TVS diode.
    Discovered the issue when building and testing the prototype. The circuit was sinking the maximum allowed current from my power supply, and dropping the circuit down to 1V.
    [lumenlab-pcb.kicad_sch]
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2025-09-12 Wire logic level shifter with docs
    [lumenlab-pcb.kicad_sch]
2025-09-15 Exchange quad with single gate logic-level shifter
    [lumenlab-pcb.kicad_sch]
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2025-09-18 Fix series feedback resistor in schematic
    [lumenlab-pcb.kicad_sch]
2025-09-18 Add linear taper potentiometer for brightness control
    [lumenlab-pcb.kicad_sch]
2025-09-19 Add potentiometers for LED brightness and audio volume
    [lumenlab-pcb.kicad_sch]
2025-09-19 Add screw terminal and adjust formatting
    [lumenlab-pcb.kicad_sch]
2025-09-19 Add custom symbols, footprints, and 3D models
    [BarrelJack.step, LM386MX-1_NOPB.step, MP2338.step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]
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2025-09-23 Resolve conflicting GPIO ADC pin 34 for navigation left button
    [lumenlab-pcb.kicad_pcb]
2025-09-25 Fix debounce in RC circuit
2025-09-26 Add JTAG header for code upload
    [FTSH-105-01-S-DV-TR.step, lumenlab-pcb.kicad_pcb]
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2025-09-29 Replace footprints with available components, add models
    [16SEPF1000M.step, BarrelJack.step, SMAJ12CA-tvs-diode.step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]
2025-09-29 Continue making footprint changes, BOM additions
    [10TZV220M6-speaker-cap.step, 1264EY-6R8M_P3-inductor.step, 504-nav-switch.stp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]
2025-09-30 Footprint changes for package sizes and BOM additions
    [lumenlab-pcb.kicad_pcb, potentiometer.step]
2025-10-01 Finalize schematic, footprint assignments, DigiKey BOM
    [B2B-PH-K-S.step, JTAG-header.STEP, LumenLab-DigiKey-BOM.xlsx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]
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2025-10-11 Separate pcb layout into separate modules
    [lumenlab-pcb.kicad_pcb]
2025-10-11 Redesign the OLED user interface, implement USB programming
    Due to testing with a hand soldered prototype, the original design of
    using a five-way navigation tactile switch for the display navigation
    was removed due to the button's fragility. A push button can be
    registered as a push, down, and right command. The display will be
    navigated using the PS3 controller, as that was already accessible.
    USB-C periphials were added for more universal firmware updates, instead
    of requiring the use of the ESP-Prog.
    [0ZRE0005FF1C.stp, CP2102N-A02-GQFN24R.step, ESD122DMYR.step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]
2025-10-11 Replace LED strip bare THT pads with JST 3.96mm. Replace decoupling THT cap for SMD
    [B4PS-VH-jst-vh-connector.step, B6PS-VH-jst-vh-connector.step, EMZS250ARA102MJA0G-led-decoupling-cap.step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]
2025-10-11 Place power delivery, power protection, and step-down regulator
    [lumenlab-pcb.kicad_pcb]
2025-10-11 Add LDO, signal JST connector, OLED display, and UI potentiometers
    [lumenlab-pcb.kicad_pcb]
2025-10-11 Place remaining components, audo, JTAG, filters
    [lumenlab-pcb.kicad_pcb]
2025-10-11 Route traces, tune differential pair
    [lumenlab-pcb.kicad_pcb]
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2025-10-11 Promote to four-layer board
    [lumenlab-pcb.kicad_pcb]
2025-10-11 Setup for trace routing, DRC fixes
    [lumenlab-pcb.kicad_pcb]
2025-10-11 Replace toggle switch with rocker switch because board real estate is expensive
    [RockerPowerSwitch.step, lumenlab-pcb.kicad_pcb]
2025-10-11 Complete redesign of board to include 8Ω speaker
    [Speaker.step, lumenlab-pcb.kicad_pcb]
2025-10-11 YARD (yet another redesign) - Keep light current paths short and together
    [lumenlab-pcb.kicad_pcb]
2025-10-13 Copper pour GND and 3.3V, add vias to all nets
    [lumenlab-pcb.kicad_pcb]
2025-10-14 Finalize PCB, address all DRC issues
    [audio-speaker-connector.step, lumenlab-pcb.kicad_pcb]
2025-10-15 Make timer inheritable vs composable
    [lumenlab-pcb-job.gbrjob]
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2025-10-18 Remove secrets file, since using sockets was replaced with usb serial
    [system-config.h]
2025-10-19 Center heading text, fix game selection bug
    [engine.cpp]
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2025-10-27 Multicore setup, fix laggy display render, setup for player response
    [engine.cpp, player.cpp, system-config.h]
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2025-10-30 Fix mismatched controller button, DRY up logic
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2025-11-28 Fix controller initialization on startup
    [engine.cpp]
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2025-12-06 Extrude lid of enclosure
    [lumenlab-pcb.kicad_pcb]
2025-12-06 Add lip around front face
    [lumenlab-pcb.kicad_pcb]
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2025-12-06 Fix slit dimensions for SPST power switch
    [lumenlab-pcb.kicad_pcb]
2025-12-07 Additional fit adjustment for OLED display
    [lumenlab-enclosure-lid.3mf]
2026-01-03 Revert "Merge pull request #27 from ericmcdaniel/engine/color-correction"
    This reverts commit 62b01568730847356b4a8409d70c1d33c7528796, reversing
    changes made to d1a8a9e5cdb33f83ad9aee897295abea15506cd3.
    [system-config.h]
2026-01-10 Fine tune gamma, skip color correction on virtualization
    [system-config.h]
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2026-01-12 Add mounting hole, adjust dimensions
    [lumenlab-enclosure-body.3mf, lumenlab-enclosure-lid.3mf, lumenlab-enclosure.3mf]
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2026-01-13 Complete body, add branding, ventilation
    [lumenlab-enclosure-body.3mf, lumenlab-enclosure-lid.3mf, lumenlab-enclosure.3mf]
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2026-01-16 Create production files and docs
    [lumenlab-enclosure-body.3mf, lumenlab-enclosure-lid.3mf, lumenlab-enclosure.3mf]
2026-01-23 Move Config to Core module
    [configuration.h]
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2026-02-05 Focus GameOver lights on collision site
    [driver.h]
2026-02-11 Ensure score resets on game change, bump to C++20
    [driver.h]
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2026-02-16 Move version number to .data segment
    [configuration.h]
2026-02-19 Set system config from Preferences
    [configuration.h]
2026-02-19 Fix bug crashing when pool is at max capacity
2026-02-19 Set configuration for boundaries/dimensions
    [configuration.h]
2026-02-19 Fix dimensions call
    [configuration.h]
2026-02-21 Fix data type cast mismatch
    [engine.cpp]
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2026-02-27 Replace PS4 lib, add guards
    [engine.cpp]
2026-02-28 Fix bug with high score, buffer size
    [engine.cpp]
2026-02-28 Fix issue with display being inactive on late PS3 controller pair
    [engine.cpp]
2026-02-28 First multi-target build with different controllers
    [configuration.h]
2026-03-01 Fix runtime crash on PS3 controller init
    [engine.cpp]
2026-03-03 Create ci/cd pipeline for multi-artifact deployment
    [configuration.h]
2026-03-05 Map PS4 buttons, fix initialization
    [engine.cpp]
2026-03-23 Setup sketch of led strip bracket
    [led-strip-mount-and-bracket.FCStd]
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2026-03-23 Reshape bracket for mount
    [led-strip-mount-and-bracket.FCStd]
2026-03-24 Add seat for acrylic sheet
    [led-strip-mount-and-bracket.FCStd]
2026-03-24 Add rail for support
    [led-strip-mount-and-bracket.FCStd]
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2026-03-24 Adjust clearances, prototype-print ready
    [led-strip-mount-and-bracket.FCStd]
2026-03-25 Add snap-fit joints for acrylic fit
    [endcap-left.3mf, led-strip-mount-and-bracket.FCStd, led-strip-mount-bracket-full.3mf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]
2026-03-25 Add model image and description
    [led-strip-mount-and-bracket.FCStd]
2026-03-25 Redesign after failed test. Adj tolerances
    [endcap-left.3mf, led-strip-mount-and-bracket-v2.FCStd, led-strip-mount-and-bracket.FCStd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]
2026-03-26 Add endcap, mating connection, experiment with geometries
    [led-strip-mount-and-bracket-v2.FCStd]
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2026-03-27 Tighten tolerance for mating guide pin, add acrylic snap fit
    [led-strip-mount-and-bracket-v2-bracket.3mf, led-strip-mount-and-bracket-v2.FCStd]
2026-03-28 Add pivot for 135-degree turn
    [led-strip-mount-and-bracket-v2.FCStd]
2026-03-28 Fix extrusion angle
    [led-strip-mount-and-bracket-v2.FCStd]
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2026-04-08 Move speaker for PCB clearance
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2026-04-18 Move logo/branding to top face for no ctrl saddle
    [lumenlab-platform-enclosure-v3-body-no-controller-saddle.3mf]
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2026-04-26 Make micro adjustments for the controller's snap fit.
    [lumenlab-platform-enclosure-v3-body-with-controller-saddle.3mf]
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2026-04-26 Strengthen clip
    [led-strip-mount-and-bracket-v3.FCStd]
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2026-05-01 Setup inter-locking snap mechanism
    [led-strip-mount-and-bracket-v3.FCStd]
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2026-05-02 Ensure mating pin clearances is tight fit
    [led-strip-mount-and-bracket-v3.FCStd]
2026-05-02 Adjust bracket shape to reduce amount of diffuser sheets needed
    [led-strip-mount-and-bracket-v3.FCStd]
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2026-05-06 Add raw geometry of saddle for finishing vinyl center support
    [led-strip-mount-and-bracket-v3.FCStd]
2026-05-08 Get raw working portotype of the rail clamp
    [led-strip-mount-and-bracket-v3.FCStd]
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2026-05-09 Fix sizing issue after first test print
    [led-strip-mount-and-bracket-v3.FCStd, plywood-retention-clip.3mf]
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2026-05-11 Add mirror and endcap for connection reversal
    [led-strip-mount-and-bracket-v3.FCStd]
2026-05-14 Add friction detent to hold acrylic panel snug
    [led-strip-mount-and-bracket-v3.FCStd]
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2026-05-14 Additional fit test, loosened
    [led-strip-mount-and-bracket-v3.FCStd]
2026-05-15 Additional additional fit test. Tighter
    [led-strip-mount-and-bracket-v3.FCStd, led-strip-v3-bracket-only__dark.3mf]
2026-05-16 Fix linear pattern for LED cavity fillet
    [led-strip-mount-and-bracket-v3.FCStd]
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2026-05-19 Strengthen enclosure strength, make micro adjustments to port sizing
    [lumenlab-platform-enclosure-v3-body-with-controller-saddle.3mf, lumenlab-platform-enclosure-v3-lid.3mf]
2026-05-20 Fix scale functions, add addl mounting points
    [led-strip-mount-and-bracket-v3.FCStd, led-strip-v3-bracket-only__dark.3mf, led-strip-v3-bracket-w-endcap__dark.3mf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]
2026-05-21 Modularize colored print objects
    19 hour print job reduced to 9 hours
    [lumenlab-platform-enclosure-branding.3mf, lumenlab-platform-enclosure-v3-body-with-controller-saddle.3mf, lumenlab-platform-enclosure-v3-lid.3mf]
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2026-05-22 Shrink LED cell size after connecting multiple test prints
    [led-strip-mount-and-bracket-v3.FCStd, led-strip-v3-bracket-only__dark.3mf, led-strip-v3-bracket-w-endcap__dark.3mf]
2026-05-30 Fix extruded connector pins in endcap
    [led-strip-mount-and-bracket-v3.FCStd, led-strip-v3-bracket-mirrored__dark.3mf, led-strip-v3-bracket-only__dark.3mf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]
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2026-06-30 Scale data structure replacement for chain replacement
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2026-10-14 Replace JST VH with PTH to solder pigtail extensions
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2026-10-16 Set missing pin BLK
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2026-10-17 Fix ESD diode nets
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2026-10-21 Fix shared nets and internal regulators
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2026-10-22 Replace/modify component footprints
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2026-10-27 Replace inductor footprint for in stock component
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2026-11-01 Replace pin header with Molex Mini Fit
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2026-11-01 Replace rocker switch with latching push button
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2026-11-04 Fix power topology from ERC, replace latching power button
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
